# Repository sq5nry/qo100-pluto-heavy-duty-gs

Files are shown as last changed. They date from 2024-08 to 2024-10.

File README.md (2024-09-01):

### qo100-pluto-heavy-duty-gs



# Hello fellow QO-100 aficionados,
Here's another realization of a ground station based on <a href="https://wiki.analog.com/university/tools/pluto/hacking/hardware#revision_b" target="_blank">Pluto</a>. Designed as a sturdy box to be thrown on your roof requires just a single Ethernet cable to talk to. It hosts the great <a href="https://github.com/F1ATB/Remote-SDR" target="_blank">F1ATB Remote-SDR</a> web-based transceiver but when roaming in your LAN you can also enjoy the <a href="https://www.sdr-radio.com/console" target="_blank">G4ELI SDR Console</a> desktop application. Pluto is running on a customized firmware from <a href="https://www.f5uii.net/wp-content/uploads/2021/03/pluto.zip" target="_blank">F5UII</a>. Assemblage of assorted open-source candies makes for a comfortable phone operation.

The device has four panel sockets:
- **RJ-45**: Ethernet+PoE
- **N**: 2.4GHz transmitter output
- **F**: input from LNB
- **SMA**: GPS active antenna

Features:
- operation via a web browser incl. full duplex and live waterfall display
- direct network access to Pluto for 3rd party applications
- push-to-talk automation
- frequency stability from GPS Disciplined Oscillator
- power from PoE only

:warning:Remote operation possible after meeting <a href="https://forum.amsat-dl.org/index.php?thread/3234-remote-operation-via-qo-100/" target="_blank">AMSAT requirements</a>. For the on-demand immediate shutdown capability I'm using a Wi-Fi plug to cut off AC from the PoE injector.

| deployment example | inside the box |
|---|---|
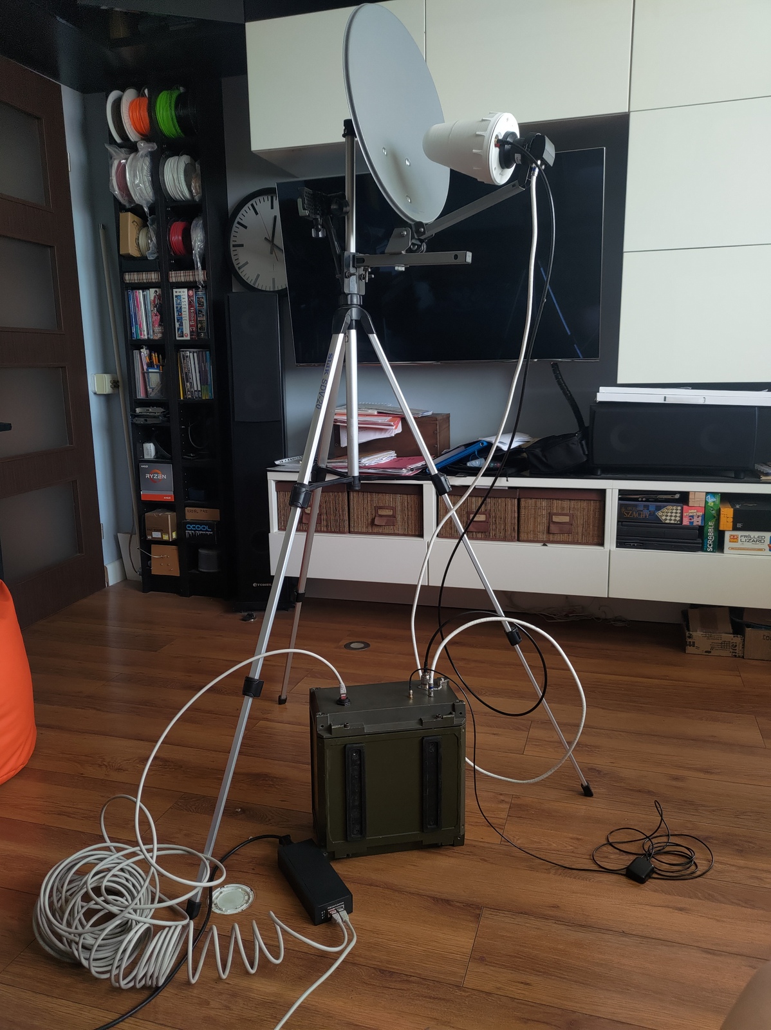
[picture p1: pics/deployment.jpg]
overview
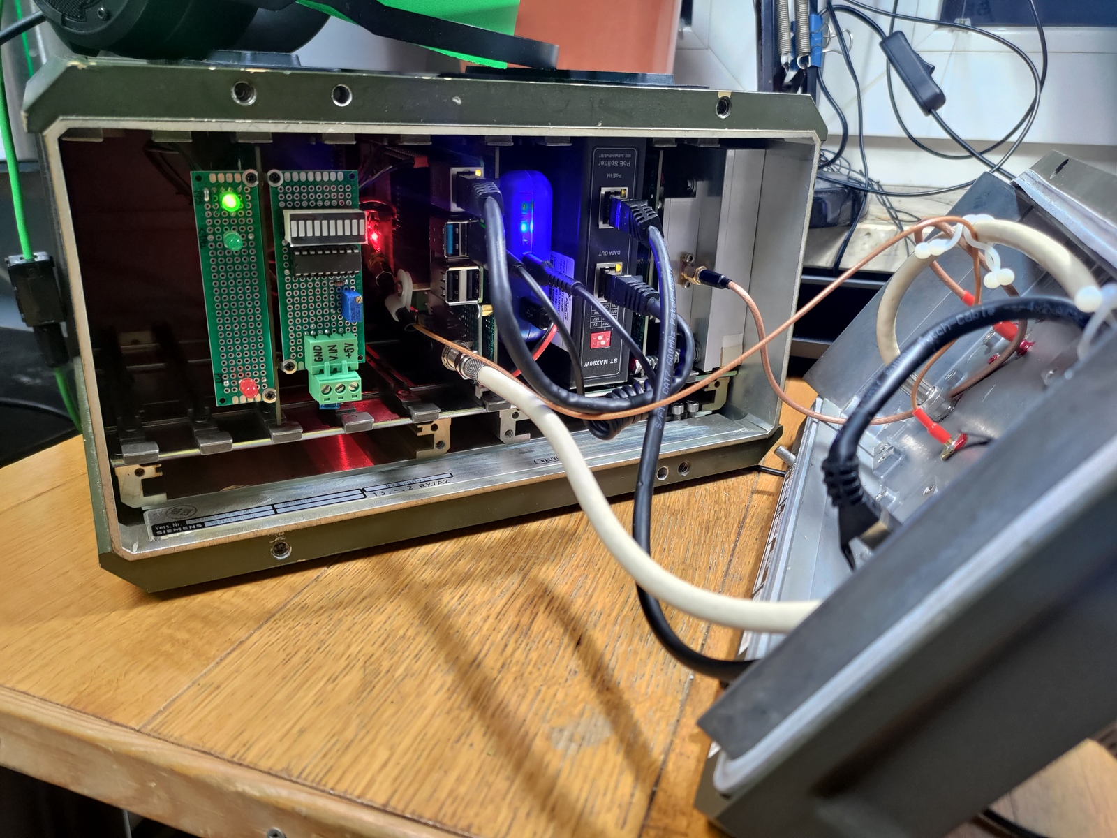
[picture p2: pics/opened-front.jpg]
interior
|  |  |

# Operation
1. Connect to a router with DHCP server via 802.3bt PoE injector offering 90W. 15 meters of SSTP CAT6 works fine. The Raspberry host will be reachable under hostname `remsdr-rpi4`. Configure remote access (eg port forwarding or <a href="https://www.zerotier.com" target="_blank">ZeroTier VPN</a> - installed)
2. Configure the web access <a href="https://remsdr-rpi4/settings.html"  target="_blank">https://remsdr-rpi4/settings.html</a> as described in <a href="https://f1atb.fr/remote-sdr-v5-raspberry-4b-or-orange-pi-image-installation/" target="_blank">https://f1atb.fr/remote-sdr-v5-raspberry-4b-or-orange-pi-image-installation</a>. Finally, navigate to the start page <a href="https://remsdr-rpi4" target="_blank">https://remsdr-rpi4</a>.
3. Alternatively, connect to Pluto locally by specifying `ip:remsdr-rpi4` as the address. Parallel use with the web interface mostly won't work.\
 For SDR Console follow the <a href="https://www.sdr-radio.com/EsHail-2" target="_blank">configuration manual</a>. Connect the USB push-to-talk button and volume knob for best experience.
 
| Arduino Due MIDI controller      |
|----------------------------------|
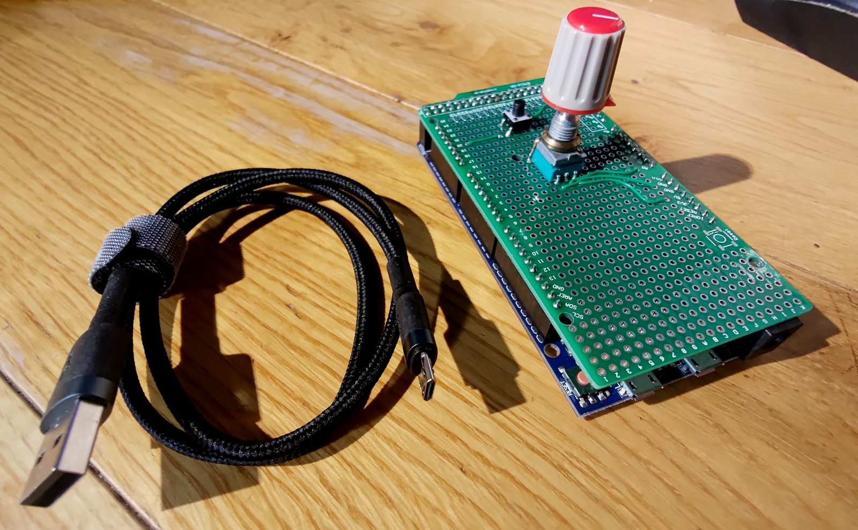
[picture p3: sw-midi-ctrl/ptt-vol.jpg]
Arduino Due MIDI controller
|  |

:warning: Smooth remote work when talking directly to Pluto (eg. SDR Console) requires a low-jitter 20Mbps connection to stream the whole 500kHz NB transponder. Web interface will settle for an ordinary 512kbps link.

# Troubleshooting
1. Restart Pluto via web interface
2. Try turning it off and on again using your remote AC switch. Pluto and software on RPi becomes operational within a minute.
3. Check GPS status on the dashboard panel inside the box
4. Log in via SSH to conduct further diagnosis

# Service manual
General block diagram: [main.pdf](hw-block-diagrams/main.pdf)

## Pluto SDR
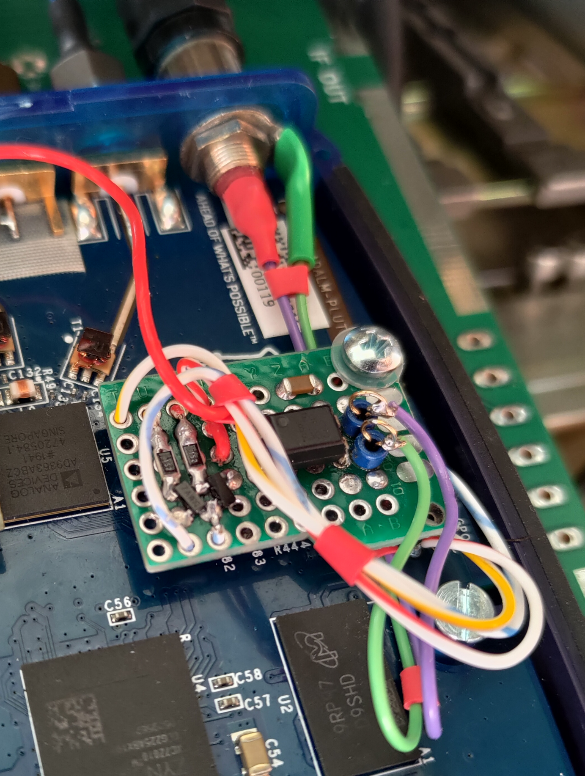
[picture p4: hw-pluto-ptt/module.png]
Built on top of rev. 'B' with two modules added inside the Pluto enclosure: external clock input and PTT output. Flashed with a firmware from F5UII https://www.f5uii.net/wp-content/uploads/2021/03/pluto.zip, here used only for the PTT when working with SDR Console. PTT is active when GPO0 is high and GPO1 is low to counteract transients on Pluto boot (read more here https://hf5l.pl/adalm-pluto-do-qo100-i-nie-tylko/). Here's ready module employing an 817 optocoupler:  \
Schematics diagram: [pluto_ptt.pdf](hw-pluto-ptt/pluto_ptt.pdf)

To install this extension, drill a hole in Pluto's plastic wall and mount a Cinch connector. Fix the PCB by tightening it via existing hole with a longer screw to the mainboard with a 5mm plastic spacer.

External clock feed for Pluto is designed by DM5RM https://forum.amsat-dl.org/index.php?thread/3199-external-clock-for-adalm-pluto/. Operation hinges on a clever idea of creating a small DC component from the clock signal for switching inputs between internal oscillator (not very stable for transmitting) and external one. I've added a blue LED informing that the external clock is active. External clock is generated by GPSDO. There's a blocking capacitor before the isolating transformer as the GPSDO Si5351 output stage doesn't like DC shorts.
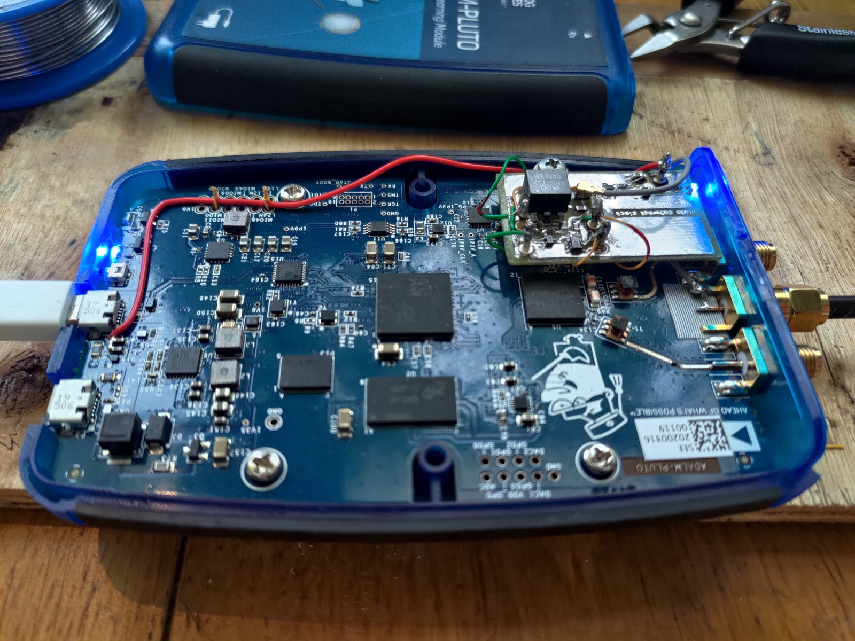
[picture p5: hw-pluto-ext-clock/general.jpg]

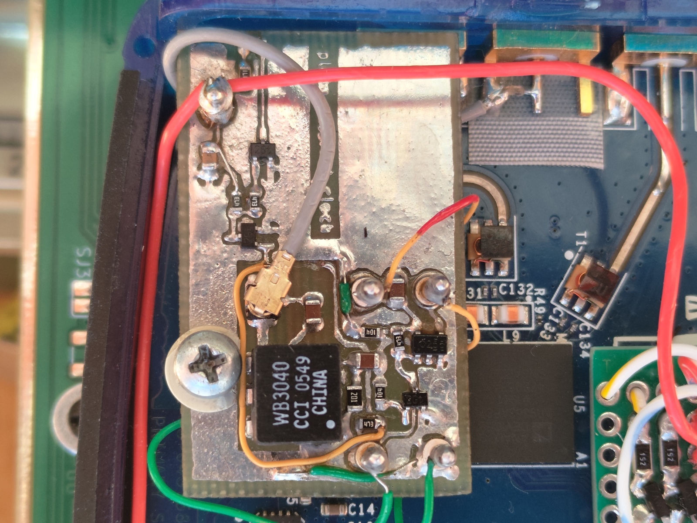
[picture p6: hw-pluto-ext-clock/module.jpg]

Schematics diagram: [pluto_clock_buffer-sch.pdf](hw-pluto-ext-clock/pluto_clock_buffer-sch.pdf) \
To install this extension, drill a hole in Pluto's plastic wall and tight fit an SMA edge connector between RX and TX ports. Place additional insulation tape to avoid bridging grounds of the SMA and that of Pluto. Use a short IPEX pigtail between the SMA connector and the board. Wire four terminal posts parallel to the onboard oscillator (1.8V, OUT, E/D, GND). Fix the PCB by tightening it via existing hole in a similar manner as the PTT extension. Place another wire from USB for 5V supply (attach to the filtering cap as shown in the picture); this line also routes to the PTT board.

A no-name 2.4GHz power amplifier delivers abt. 10W at 24V & 2A. It is mounted on a heatsink, further pressed against the enclosure wall. Internally it comprises three stages: SAW filter, MMIC pre-amplifier, and final stage with a directional coupler for forward power measurement. PTT powers the MMIC and biases the final stage hence the ~90mA current consumption.
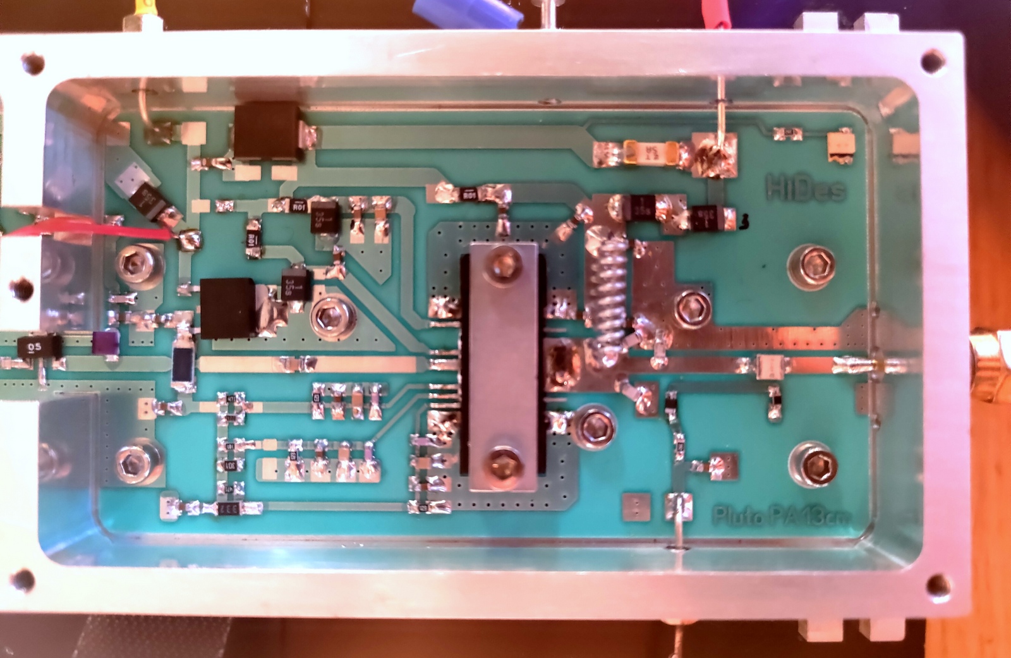
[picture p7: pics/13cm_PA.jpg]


Receive path consists of an LNB and the bias-tee. I have added an option of switching LNA voltage for H/V polarisation control, for future wideband use.
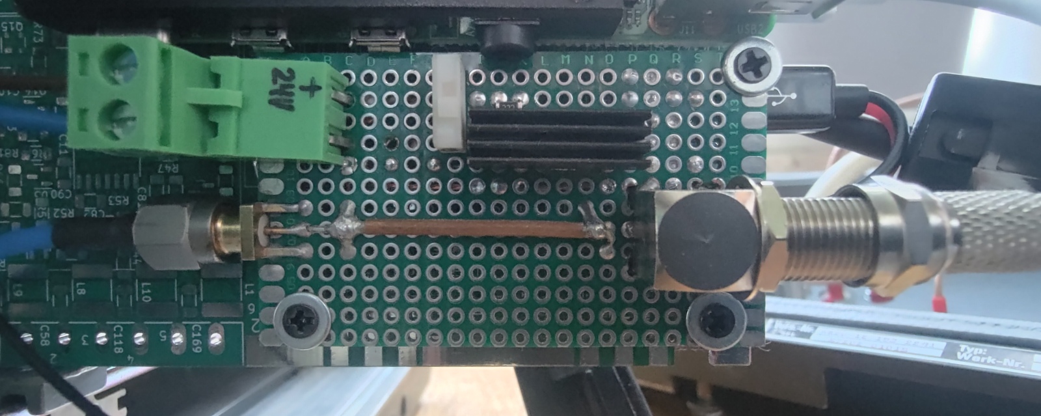
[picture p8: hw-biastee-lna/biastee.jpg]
 \
Schematics diagram: [pluto_biastee.pdf](hw-biastee-lna/pluto_biastee.pdf)

Finally, Pluto is powered from two USB plugs as advised by ADI.

## Raspberry Pi 4B
The platform is running the image from F1ATB https://f1atb.fr/remote-sdr-v5-raspberry-4b-or-orange-pi-image-installation/ and is serving a web-based Remote SDR application for receiving and transmitting via Pluto. In addition, Pluto's libiio endpoint is exposed externally so that you can connect to it via SDR Console or another client. In this mode, RPi is acting as a router between Pluto's network and RPi host. One GPIO pin is the PTT output and connects to the control board. \
Network script for exposing Pluto over RPi's ethernet interface: [ext-pluto](scripts/ext-pluto). Copy it under _/etc/network/interfaces_.

## Power and PTT control
Power supply is provided from a power regulator of the PoE splitter, preset to 24V and rated at 90W max. It goes directly to:
- the 2.4GHz power amplifier
- bias-tee and LNA power regulator
- 5V 8A regulator for all other modules

Each downstream line is protected by a resettable polymer fuse. \
Schematics diagram: [pluto_pwr_ctrl.pdf](hw-psu-ctrl/pluto_pwr_ctrl.pdf) 

| 5V regulator close-up                           |
|-------------------------------------------------|
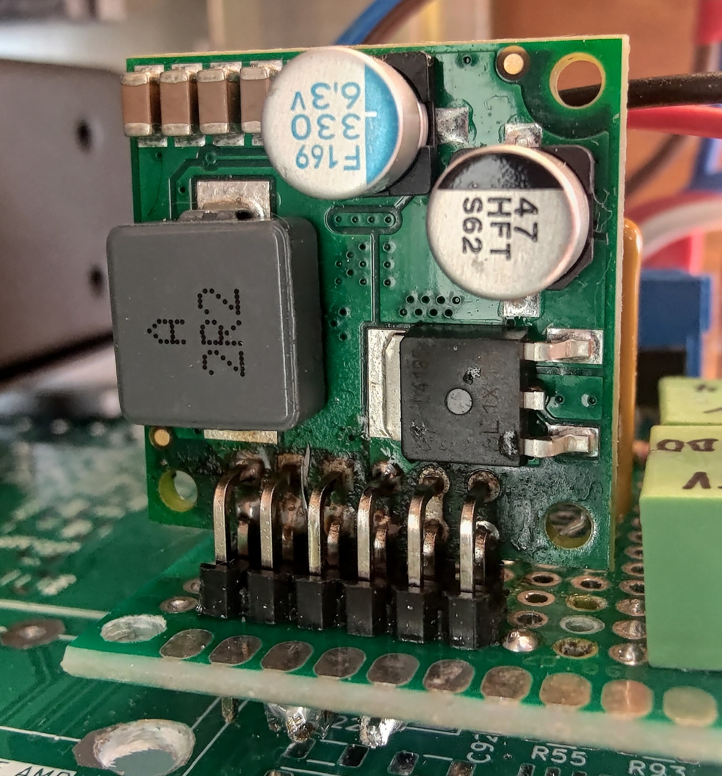
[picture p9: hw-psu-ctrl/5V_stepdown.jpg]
|  |

On the same board is mounted PTT circuitry that sums both PTT inputs (from RPi GPIO and Pluto PTT) and switches on PTT voltage for PA (abt. 90mA of current consumption). Q1 and Q2 form a high-side switch where the first stage is actually a two-transistor wired-OR gate with the second transistor being the optocoupler inside Pluto. You'll have noticed that the PTT coming from RPi's GPIO is unnecessary since Pluto tells you when it's transmitting by activating the optocoupler. Yet you might not want to upgrade the firmware which adds this and stay with the web-application only. Another reason is PTT via GPIO is asserted as soon as you click PTT on the web page and it may take tenths of milliseconds if by Pluto. This delay is virtually unnoticeable when working in SDR Console.

## GPSDO
Based on projects of W3PM (https://github.com/W3PM/GPS-Si5351-VFO-QEX-JUL-AUG-2015), SQ1GU (http://sq1gu.tobis.com.pl/pl/syntezery-dds/44-generator-si5351a) and SP3VSS (https://sp3vss.eu/moje-konstrukcje/gpsdo-generator-synchronizowany-gps/).
It generates fixed 40MHz frequency _disciplined_ by the GPS PPS signal and consists of three common-off-the-shelf modules: Arduino Nano (a clone), Si5351 synthesizer and a GPS receiver.
This is a minimal implementation of the oscillator, without display and buttons. I have introduced the following changes to the source code:
- removed handling of display and buttons
- added initial frequency correction (about 4kHz) so that at least one synchronization round can be saved. Value is hardcoded and based on a coarse one-time measurement.
- added a duplicated PPS output via GPIO for diagnostics which drives a LED at 0,5Hz and 50% duty.
- code refactoring and clean-up

Sketch: [gpsdo_minimal.ino](hw-gpsdo/gpsdo_minimal.ino) \
Block diagram: [gpsdo.pdf](hw-gpsdo/gpsdo.pdf) \
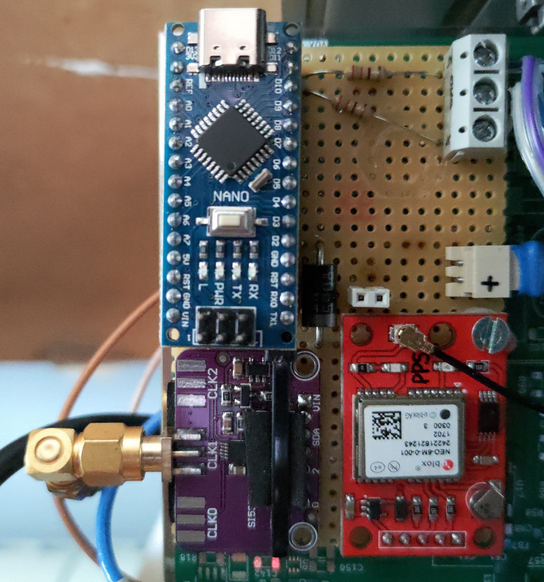
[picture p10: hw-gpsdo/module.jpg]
 \
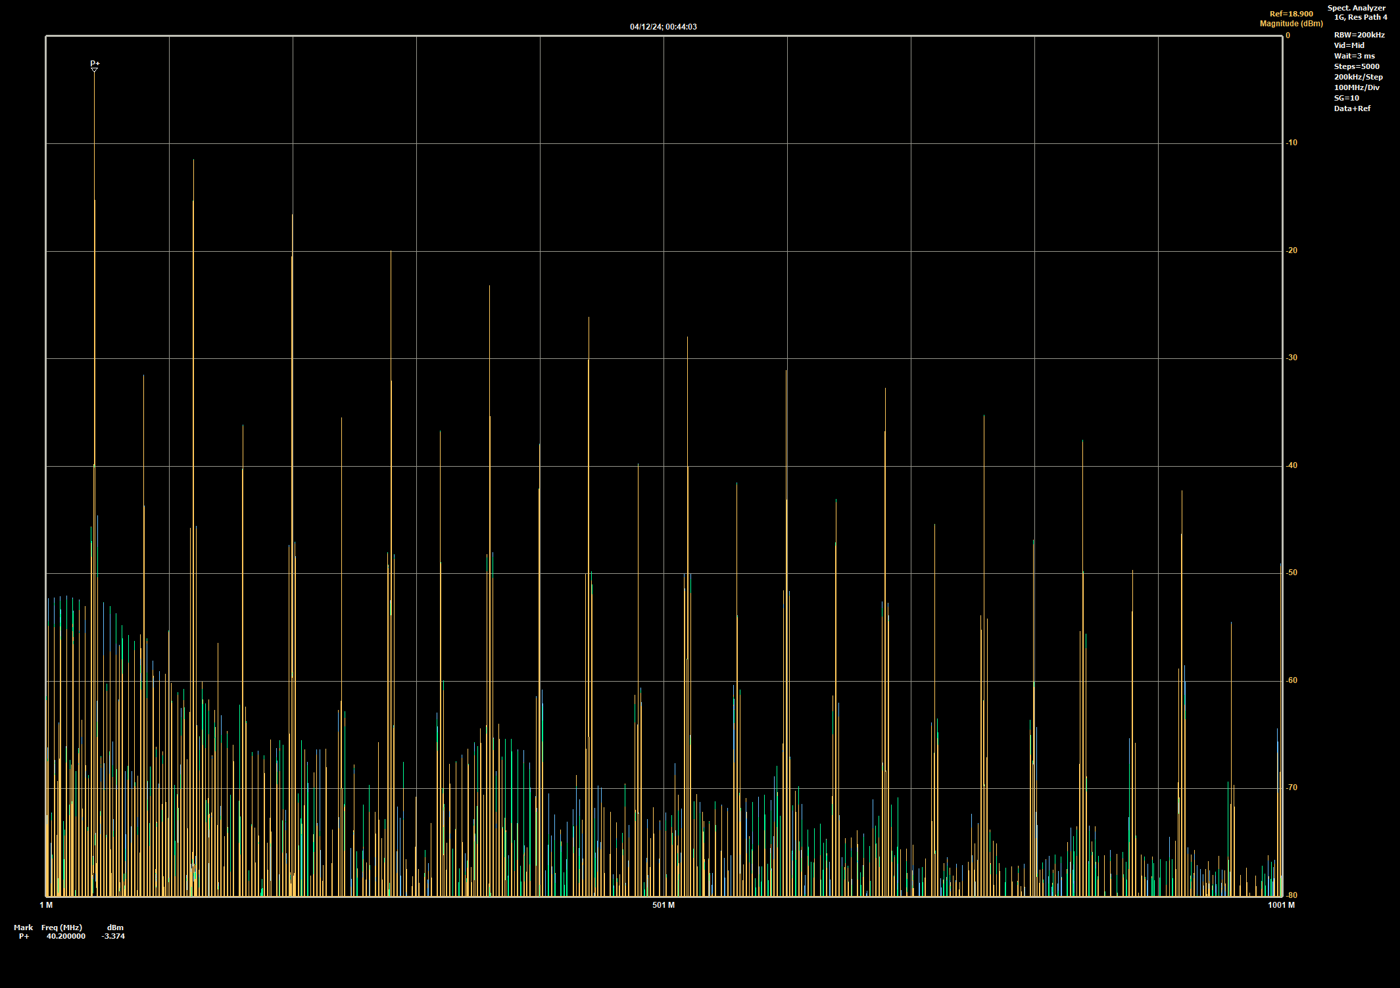
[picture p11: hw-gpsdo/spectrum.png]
Output spectrum: 
The spectrum shows a decent pattern for square wave harmonics, however 2nd order components are relatively high and decay only up to -50dBc at 1GHz. Notable are numerous spikes spaced at 200kHz, most probably being a residue from the internal Si5351 PLL stage. I haven't noticed any audible difference between this GPSDO and internal Pluto clock when working on the narrowband transponder. Wideband use might require a cleaner signal with respect to the jitter but I haven't checked that.

The diagnostics board houses two LEDs showing status of the GPSDO:
- pulse-per-second indicator showing the GPS receiver has signal
- high-accuracy (<1Hz) lock achieved

In addition:
- red LED when TX is engaged
- bargraph for TX output level
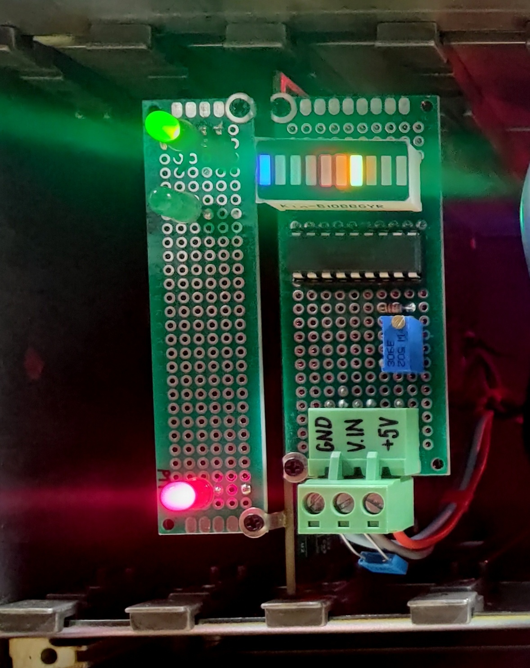
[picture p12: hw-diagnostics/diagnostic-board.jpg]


## Transmit button and volume knob
SDR Console application accepts MIDI-based devices to control transceiver functions. A simple implementation for PTT and volume knob can be realized using an Arduino module supporting a USB device natively. I've used a clone: _Due R3 SAM3X8E CORTEX-M3_. 
I based on the project presented here: https://go.musiconerd.com/code-gen-basic \
Sketch: [midi_controller_Duo_v2.ino](sw-midi-ctrl%2Fmidi_controller_Duo_v2/midi_controller_Duo_v2.ino)

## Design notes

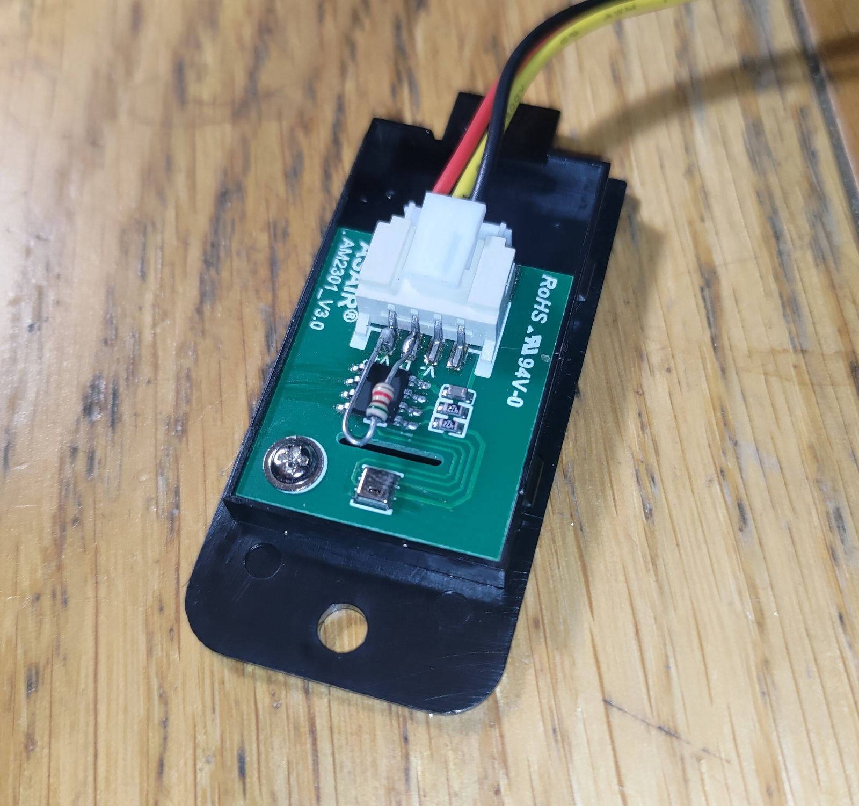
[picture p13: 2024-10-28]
pics/humidity_sensor.jpg

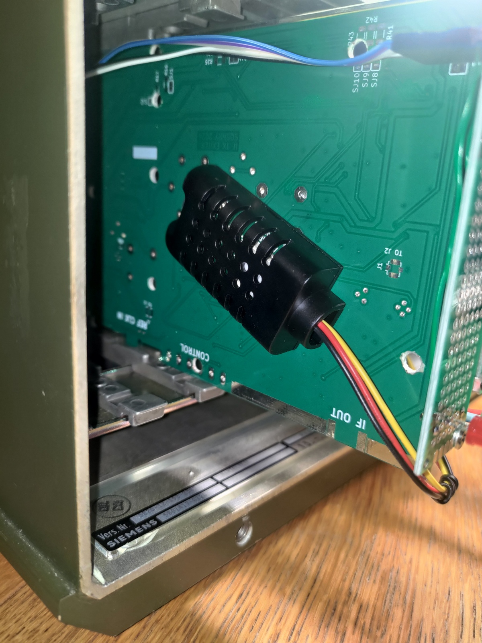
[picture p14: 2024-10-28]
pics/humidity_sensor_2.jpg

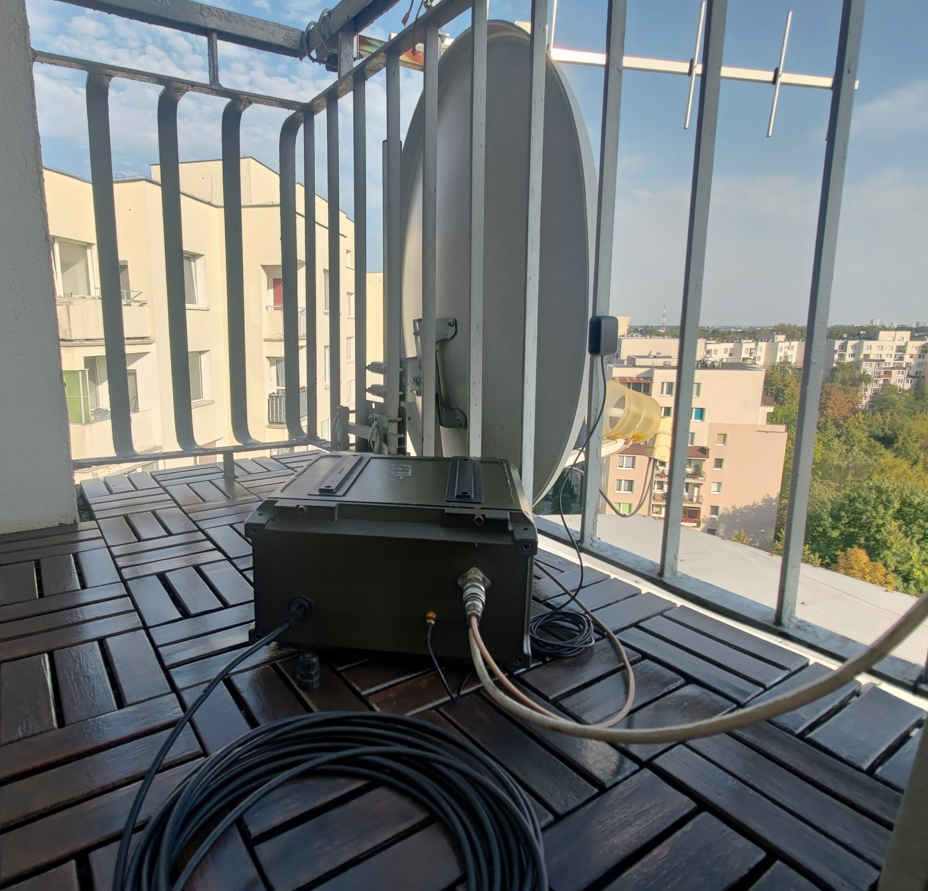
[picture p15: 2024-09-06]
pics/deployment-2.jpg

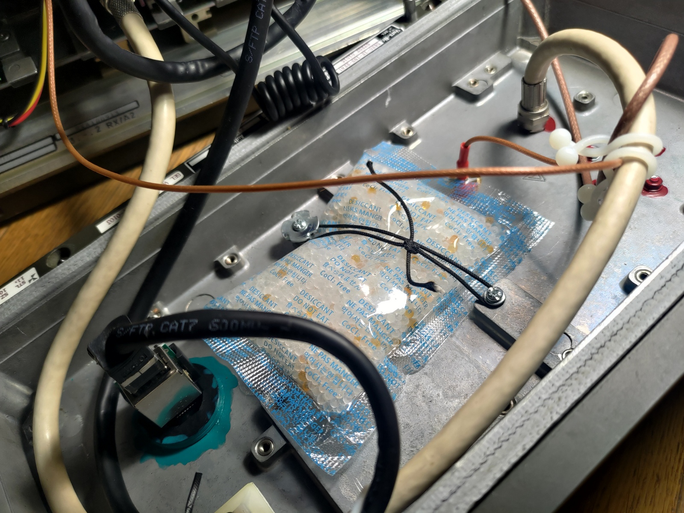
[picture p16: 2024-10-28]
pics/silica_gel.jpg

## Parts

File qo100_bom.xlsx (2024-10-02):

Pozycja | Szczegóły zakupu | Cena brutto PLN
Raspberry Pi 4 model B WiFi DualBand Bluetooth 2GB RAM 1,8GHz Indeks: RPI-14646 | BOTLAND zamówienie nr: 1142826 | 209
Obudowa-radiator Alloy Heatsink do Raspberry Pi 4B - aluminiowa - czarna Indeks: DNG-18127 | BOTLAND zamówienie nr: 1142826 | 33.15
D36V50F5 - przetwornica step-down 5V 8A - Pololu 4091 Indeks: PLL-1639 | BOTLAND zamówienie nr: 1142826 | 110
Przemysłowy rozdzielacz POE 90 W Instalacja ścienna DIN Wyjście 12 V/16 V/24 V/48 V | https://pl.aliexpress.com/item/1005005555843936.html | 200.29
Wtryskiwacz POE 90w 10G 802.3af/at/BT | https://pl.aliexpress.com/item/1005001325819218.html | 169.88
PRZEMYSŁOWA ALUMINIOWA OBUDOWA HERMETYCZNA DUŻA | https://allegro.pl/oferta/przemyslowa-aluminiowa-obudowa-hermetyczna-duza-8604877948 | 70
Antena Square GPS SMA - 3m Indeks: PSC-14775 | BOTLAND zamówienie nr: 1142826 | 26.31
Moduł GPS GY-NEO6MV2 z anteną | allegro, Sklep msalamon.pl | 27.99
Nano V3.0 z USB-C zgodny z Arduino | allegro, Sklep msalamon.pl | 28.25
SI5351A Generator sygnałów 8 kHz - 160 MHz | allegro, Sklep msalamon.pl | 28.25
Arduino DUE R3 - Atmel SAM3X8E - Cortex 84MHz - klon | Sklep ABC-RC zamówienie numer 62860 | 84.05
Płytka uniwersalna do Arduino MEGA PA02 | GOTRONIK.PL Numer zamówienia: 53071 | 12.6
Gniazdo N do obudowy herm. | https://allegro.pl/oferta/gniazdo-n-na-kabel-rg174-do-obudowy-4-sruby-15201846869 | 19.4
Pigtail SMA-wt / SMA-wt RG402 SemiFlex 20cm v1 | https://allegro.pl/oferta/pigtail-sma-wt-sma-wt-rg402-semiflex-20cm-v1-15345918431 | 37.46
GNIAZDO RJ-45 HERMETYCZNE IP67 DO OBUDOWY NA PANEL | https://allegro.pl/oferta/gniazdo-rj-45-hermetyczne-ip67-do-obudowy-na-panel-12378895084 | 80
Microconnect SSTP CAT6 15M kabel sieciowy Szary S/FTP (S-STP) | https://allegro.pl/oferta/microconnect-sstp-cat6-15m-kabel-sieciowy-szary-s-ftp-s-stp-15291351191 | 88.99
Microconnect 0.25m Cat7 S/FTP kabel sieciowy Czarny 0,25 m S/FTP (S-STP) | https://allegro.pl/oferta/microconnect-0-25m-cat7-s-ftp-kabel-sieciowy-czarny-0-25-m-s-ftp-s-stp-15291289192 | 38.99
RADIATOR P52317 100x150x25mm 1,4 K/W | https://allegro.pl/produkt/radiator-p52317-100x150x25mm-1-4-k-w-44661f8f-eca2-451e-b04c-e11f473a7ae2 | 26
Kabel USB - Micro USB ARKS 0.5 m Czarny spiralka | https://www.electro.pl/telefony-i-smartfony/akcesoria-do-telefonow/kable-i-przewody/kabel-usb-micro-usb-arks-0-5-m-czarny | 7.99
Gniazdo;F;żeńskie;kątowe 90°;THT;na panel FC-017 | TME Numer faktury: 1241214848 F | 7.54
RF2-06A-T-21-50-G Gniazdo;SMA;żeńskie;proste;RG178(A,B);zaciskanie;na panel Producent: ADAM TECH; Symbol producenta: RF2-06A-T-21-50-G; Zgodność RoHS | TME Numer faktury: 1241214848 F | 17
Higrometr +termometr 1-wire | https://botland.com.pl/czujniki-multifunkcyjne/1884-czujnik-temperatury-i-wilgotnosci-dht21-am2301-w-obudowie-5904422373269.html | 33.92
Desykant krzemionkowy | https://allegro.pl/oferta/orange-silica-gel-2x50g-pomaranczowy-zel-krzemionkowy-pochlaniacz-wilgoci-15242886034 | 6
Pluto rev. B | n/a
Wzmacniacz mocy 13cm | n/a
 |  | 1278.57

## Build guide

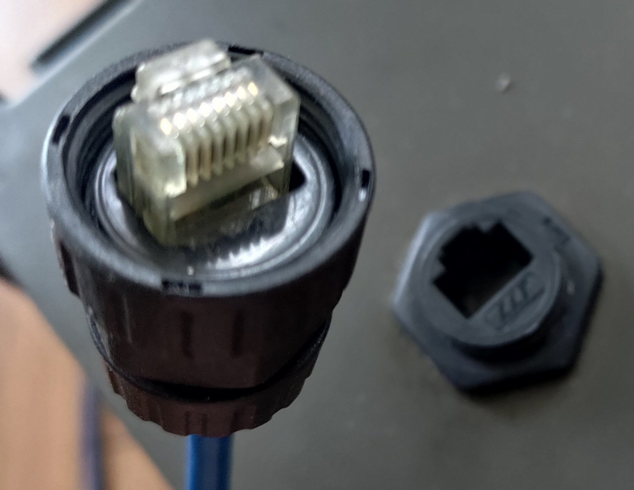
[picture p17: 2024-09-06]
pics/eth_wiring_2.jpg

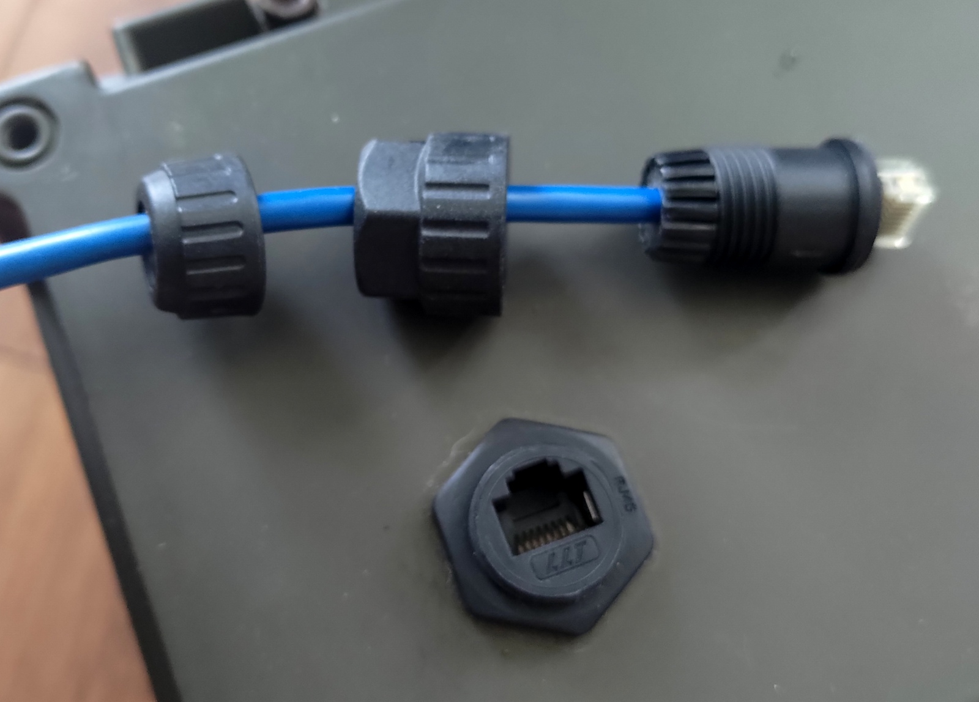
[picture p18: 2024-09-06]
pics/eth_wiring_3.jpg

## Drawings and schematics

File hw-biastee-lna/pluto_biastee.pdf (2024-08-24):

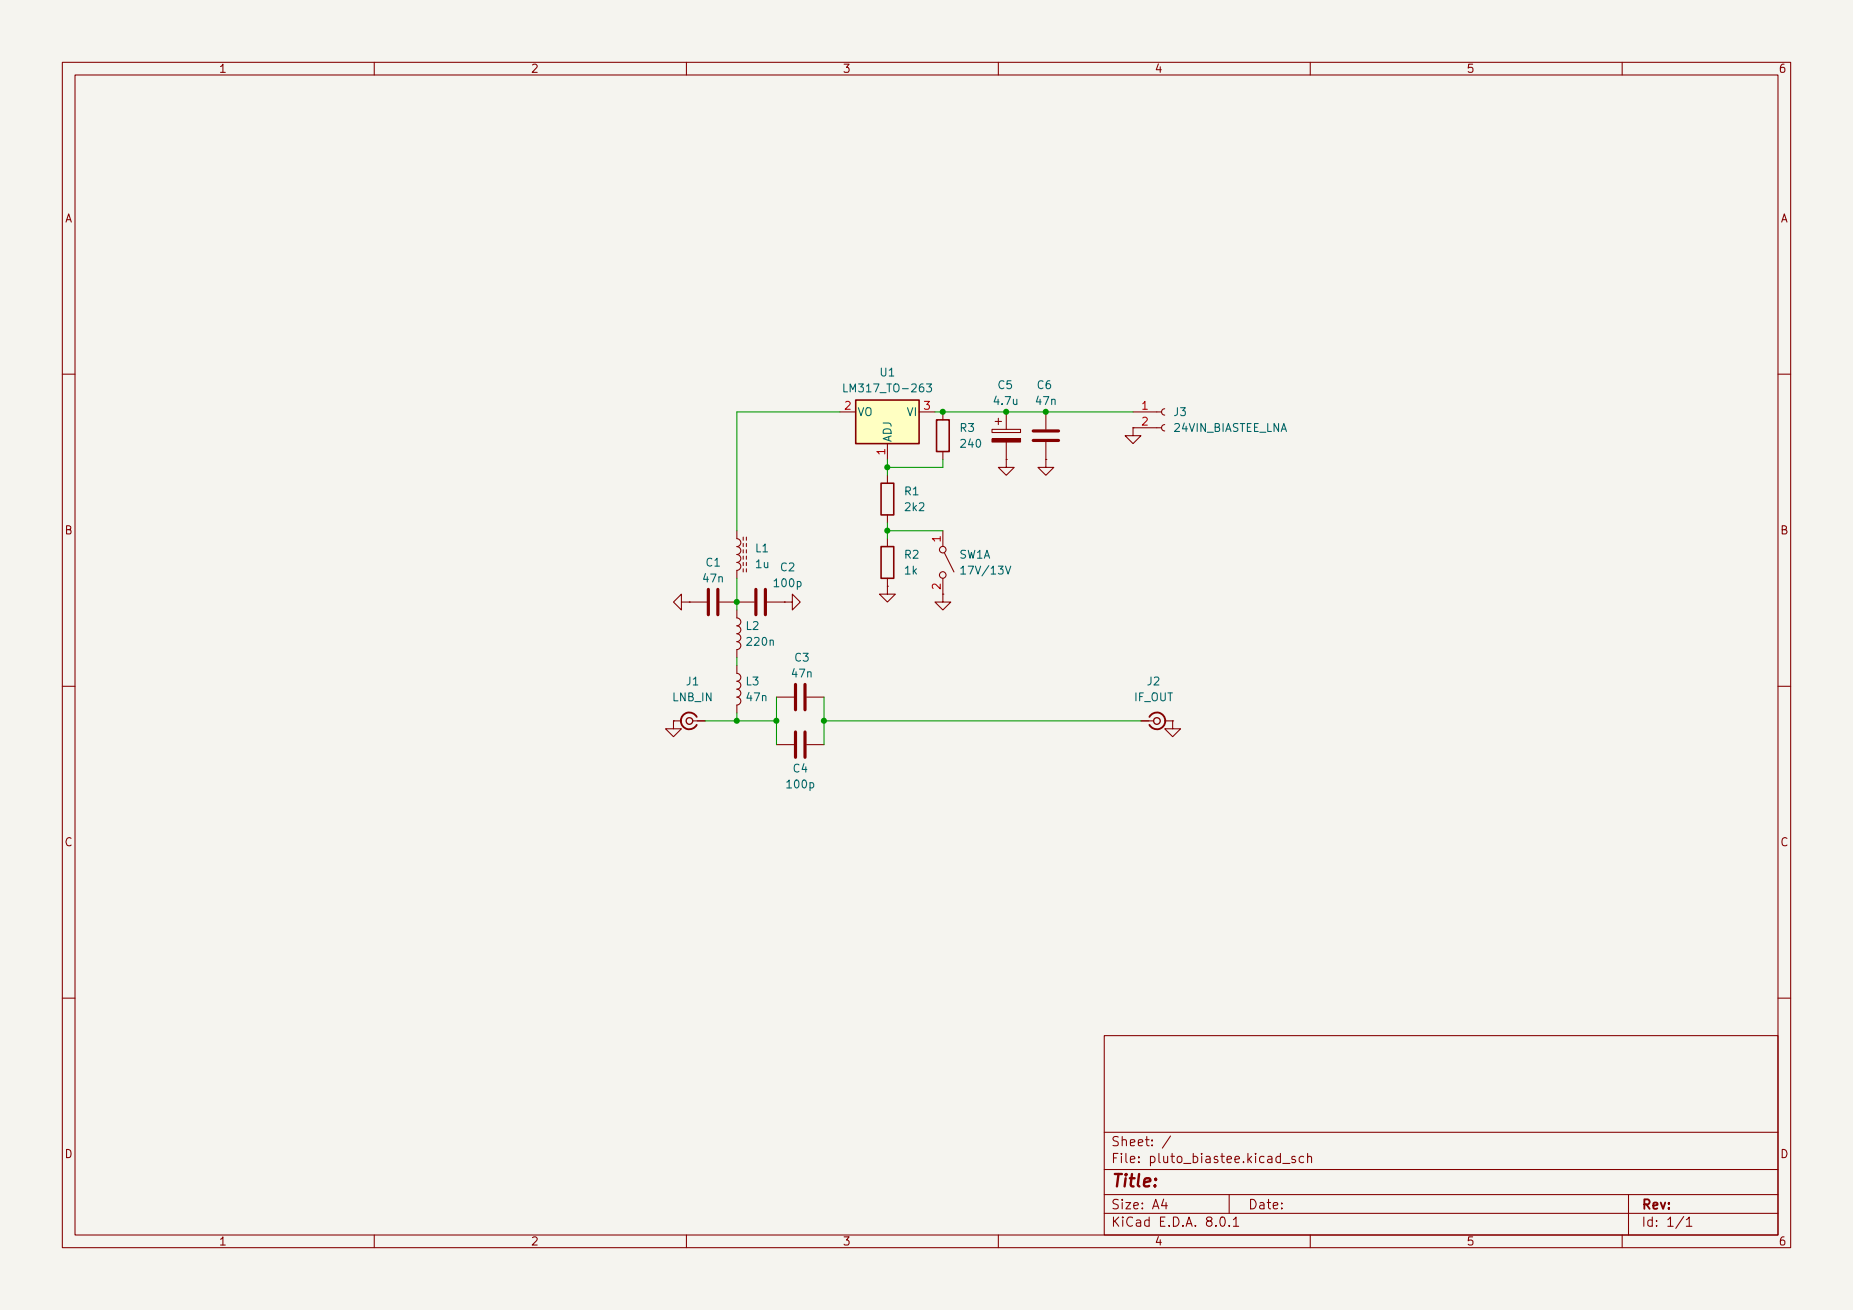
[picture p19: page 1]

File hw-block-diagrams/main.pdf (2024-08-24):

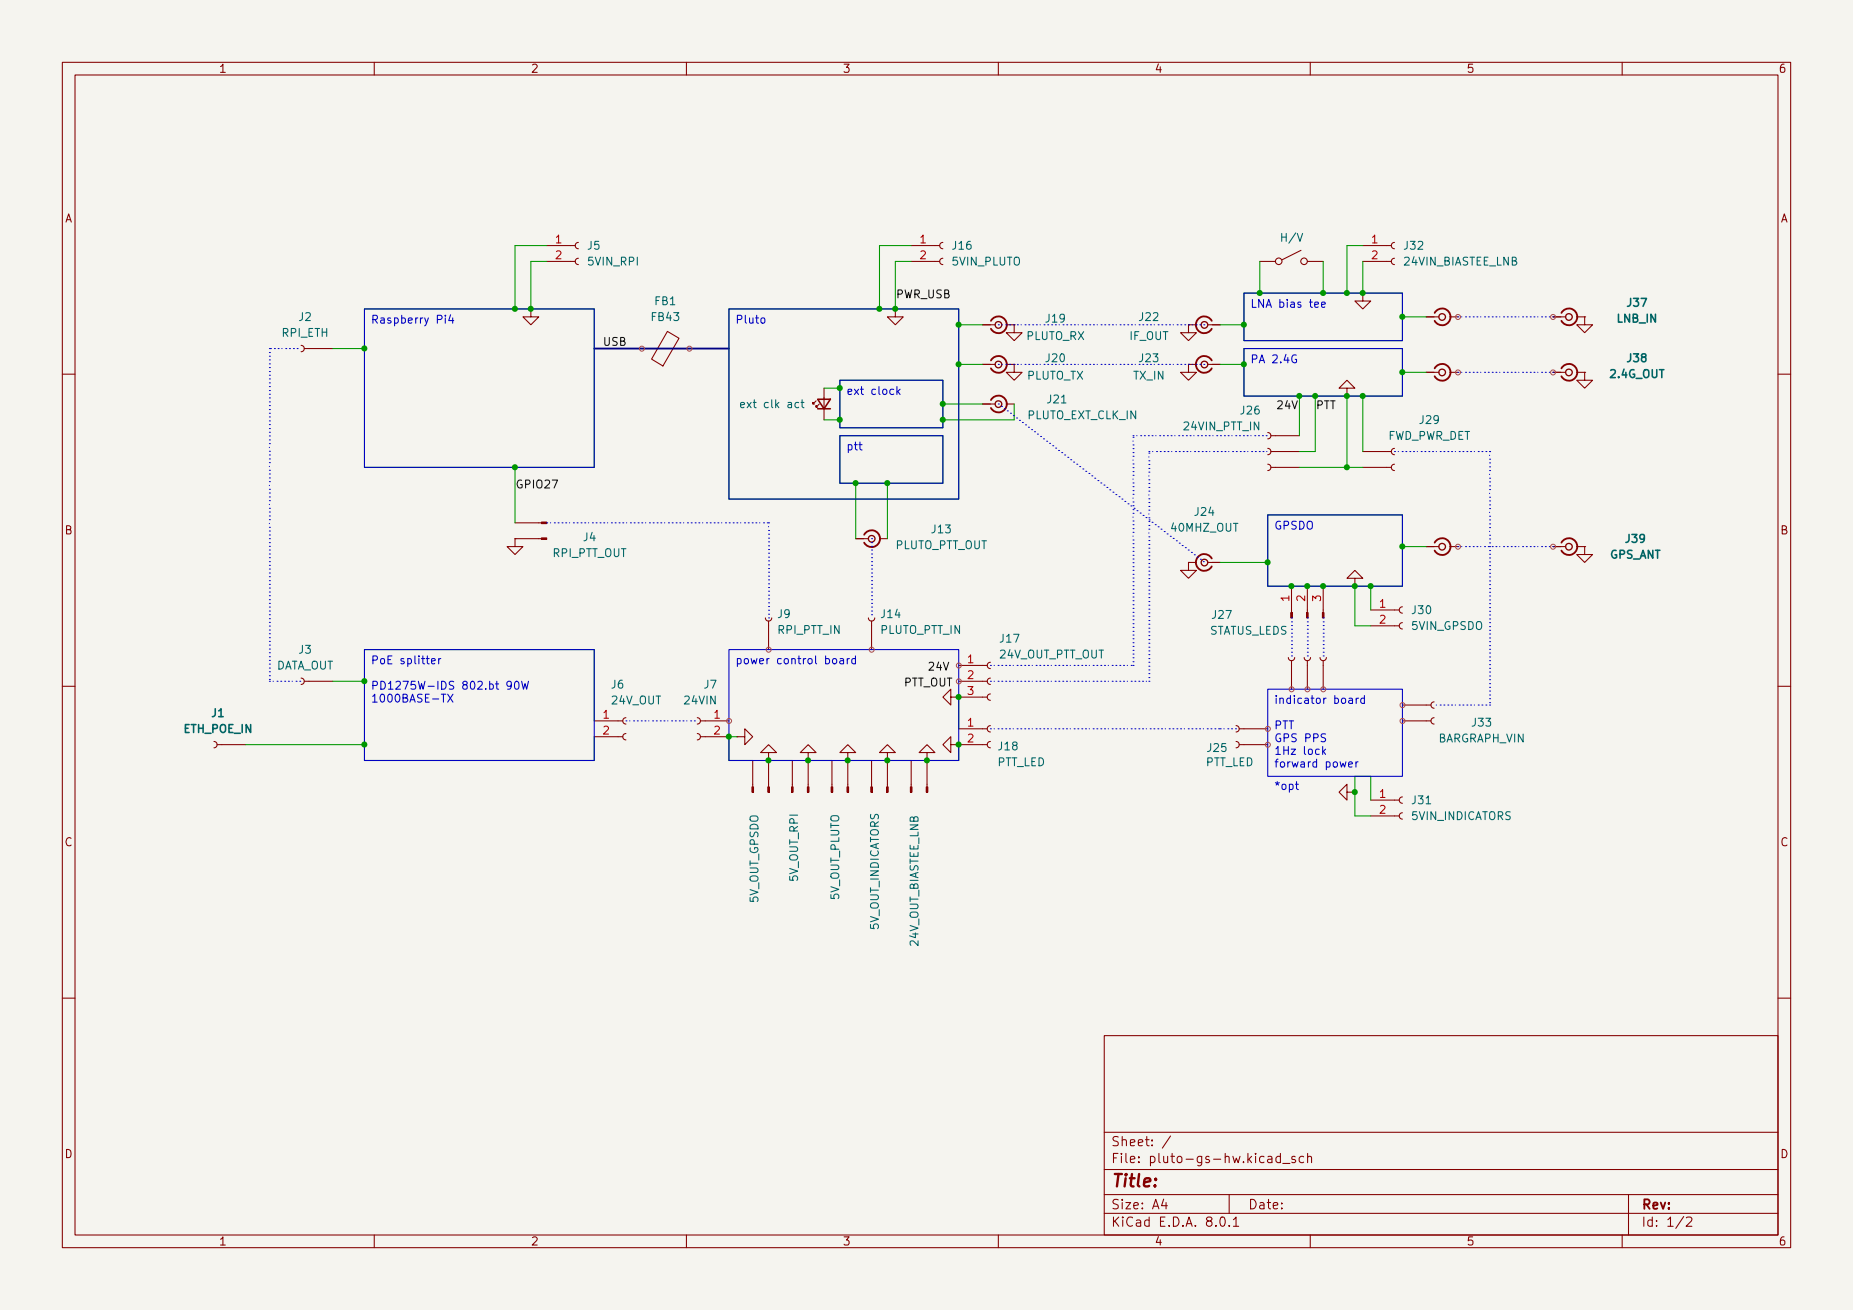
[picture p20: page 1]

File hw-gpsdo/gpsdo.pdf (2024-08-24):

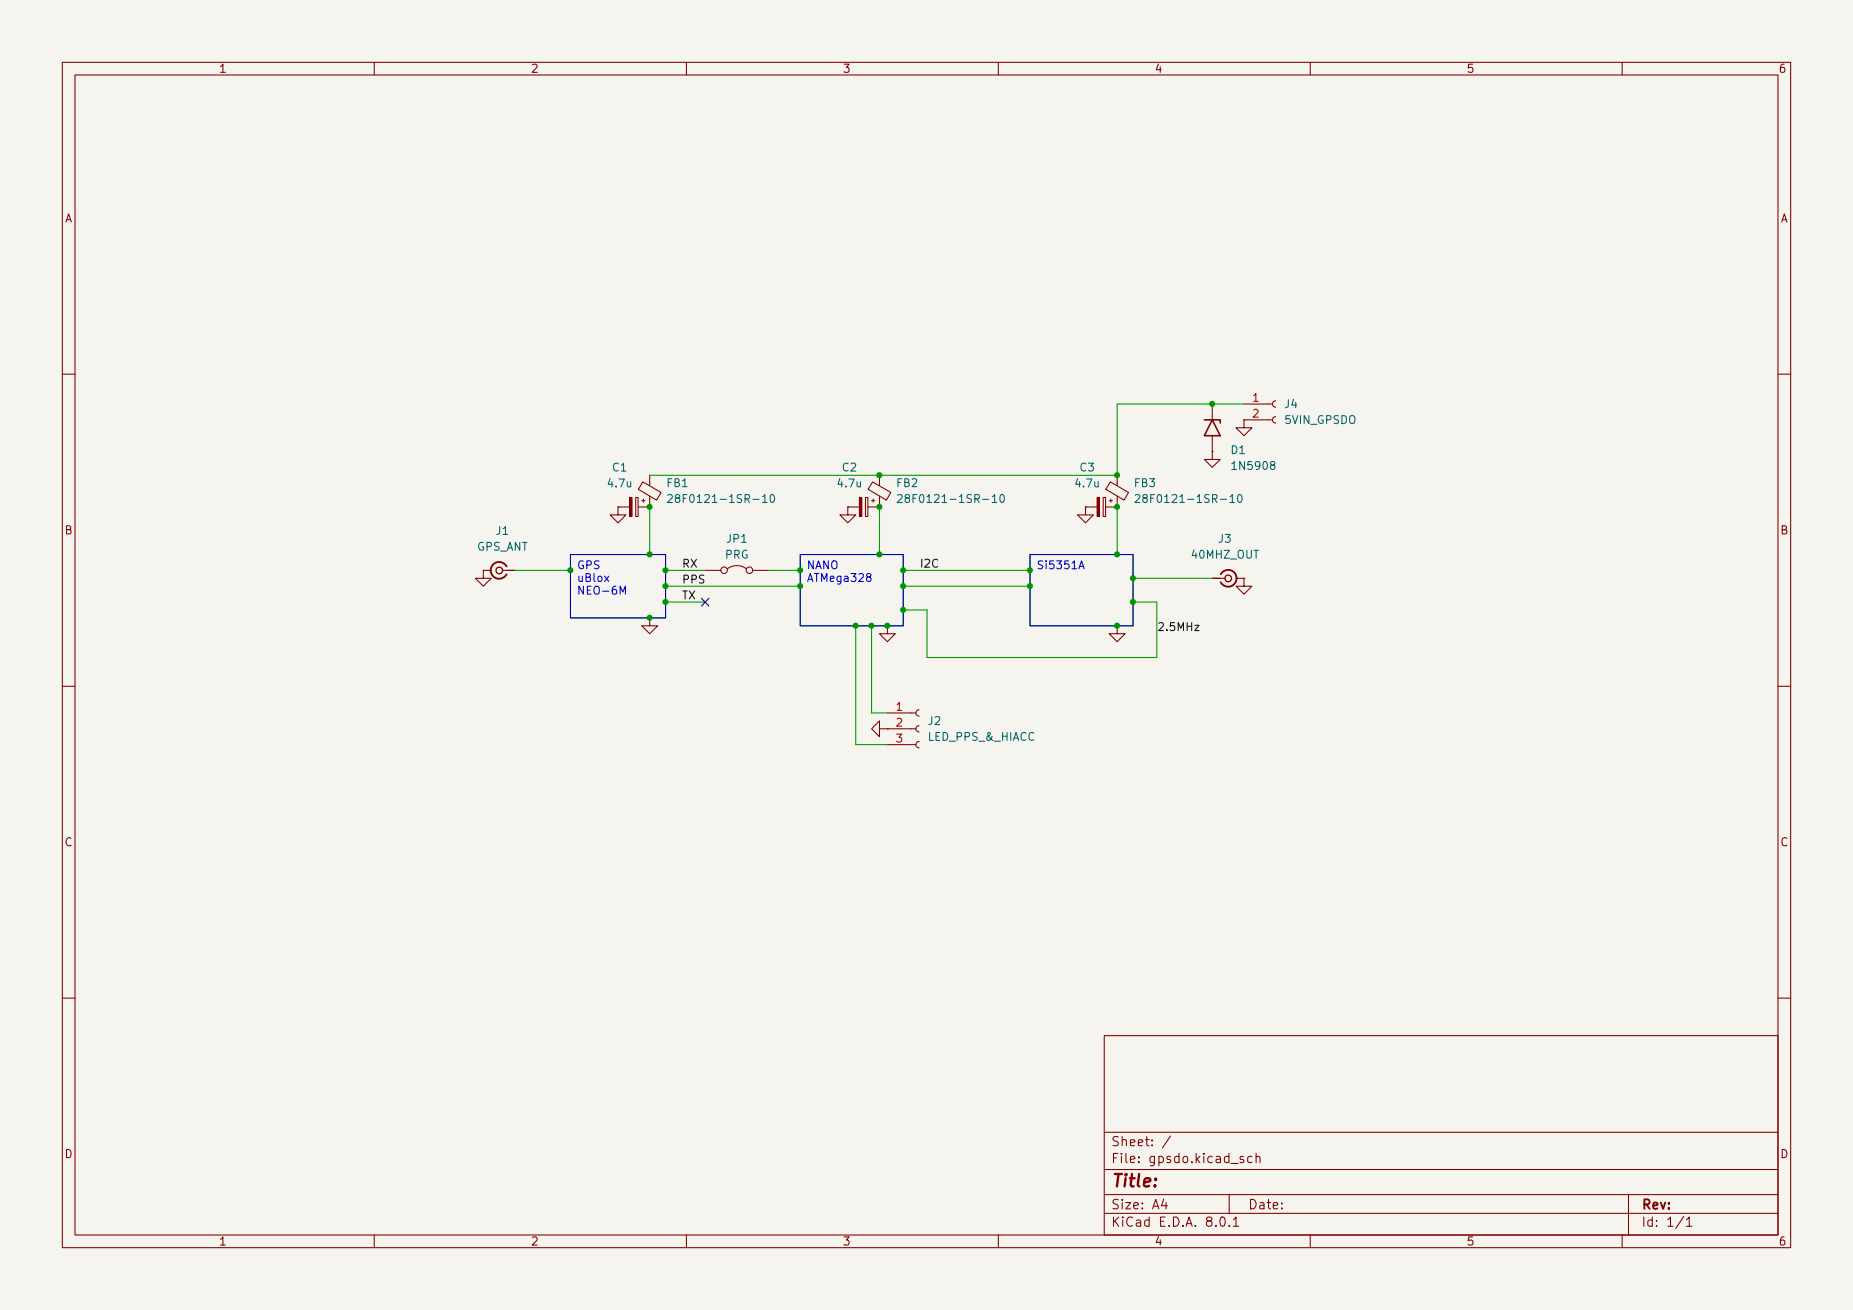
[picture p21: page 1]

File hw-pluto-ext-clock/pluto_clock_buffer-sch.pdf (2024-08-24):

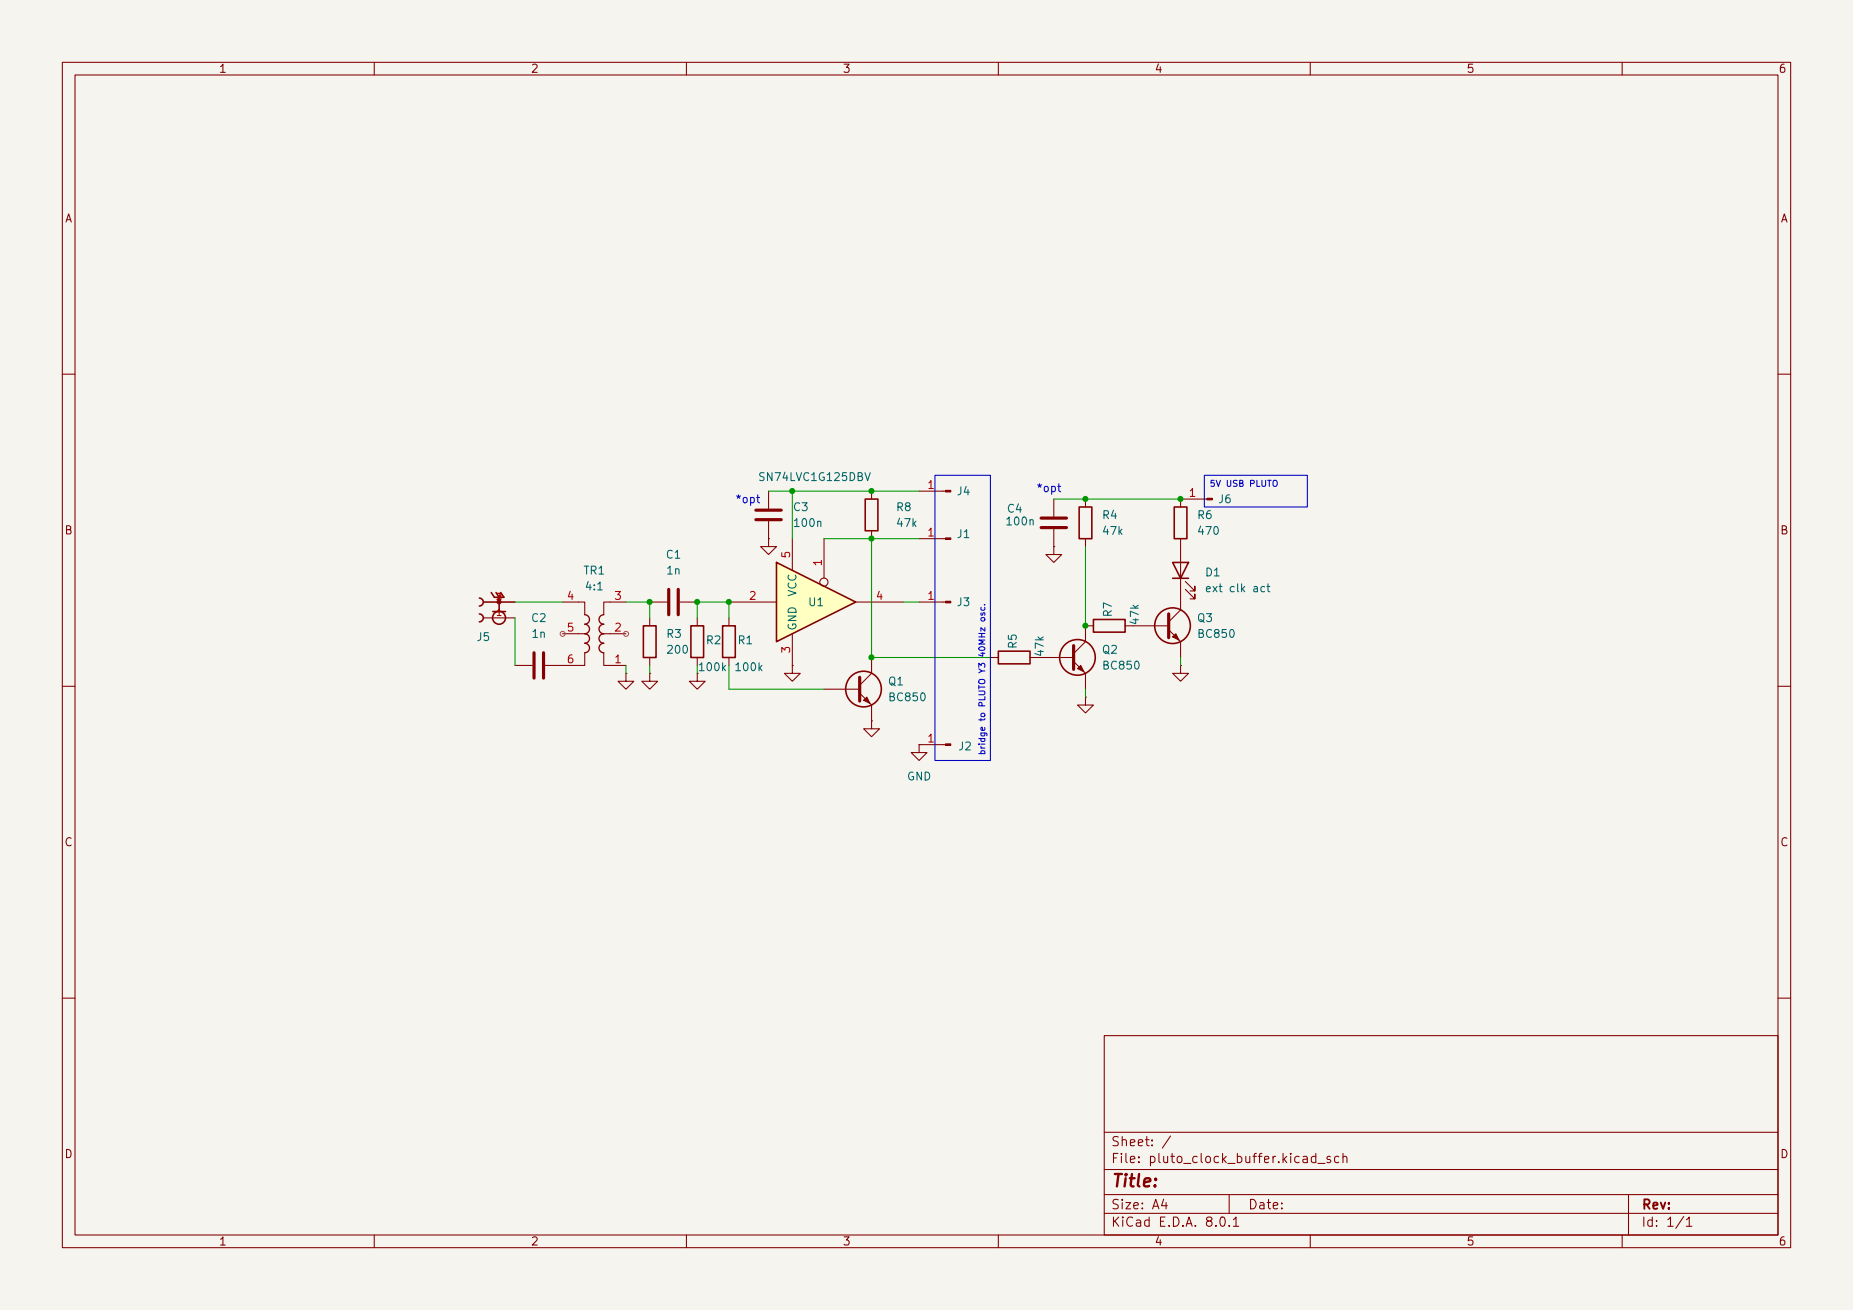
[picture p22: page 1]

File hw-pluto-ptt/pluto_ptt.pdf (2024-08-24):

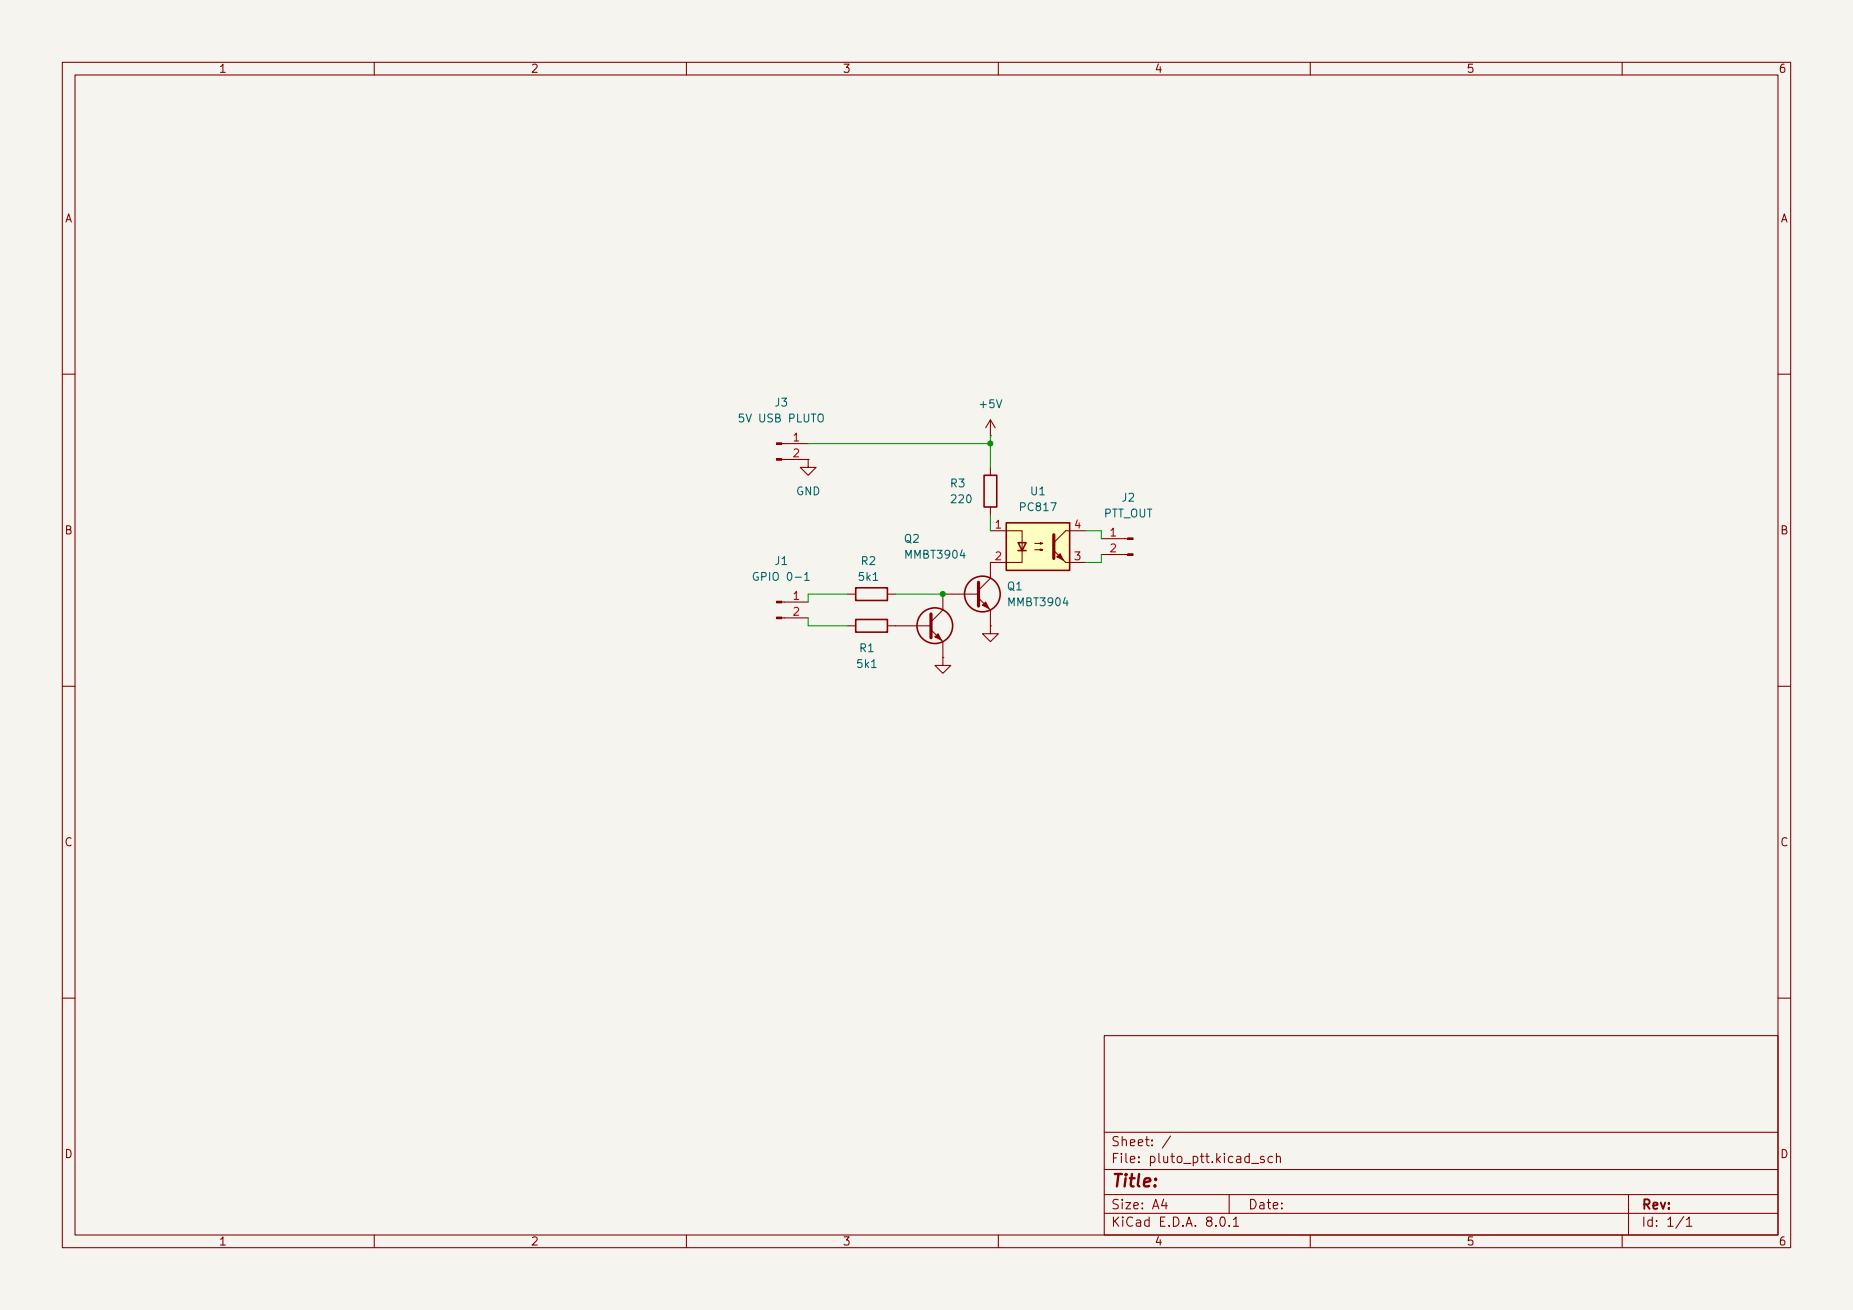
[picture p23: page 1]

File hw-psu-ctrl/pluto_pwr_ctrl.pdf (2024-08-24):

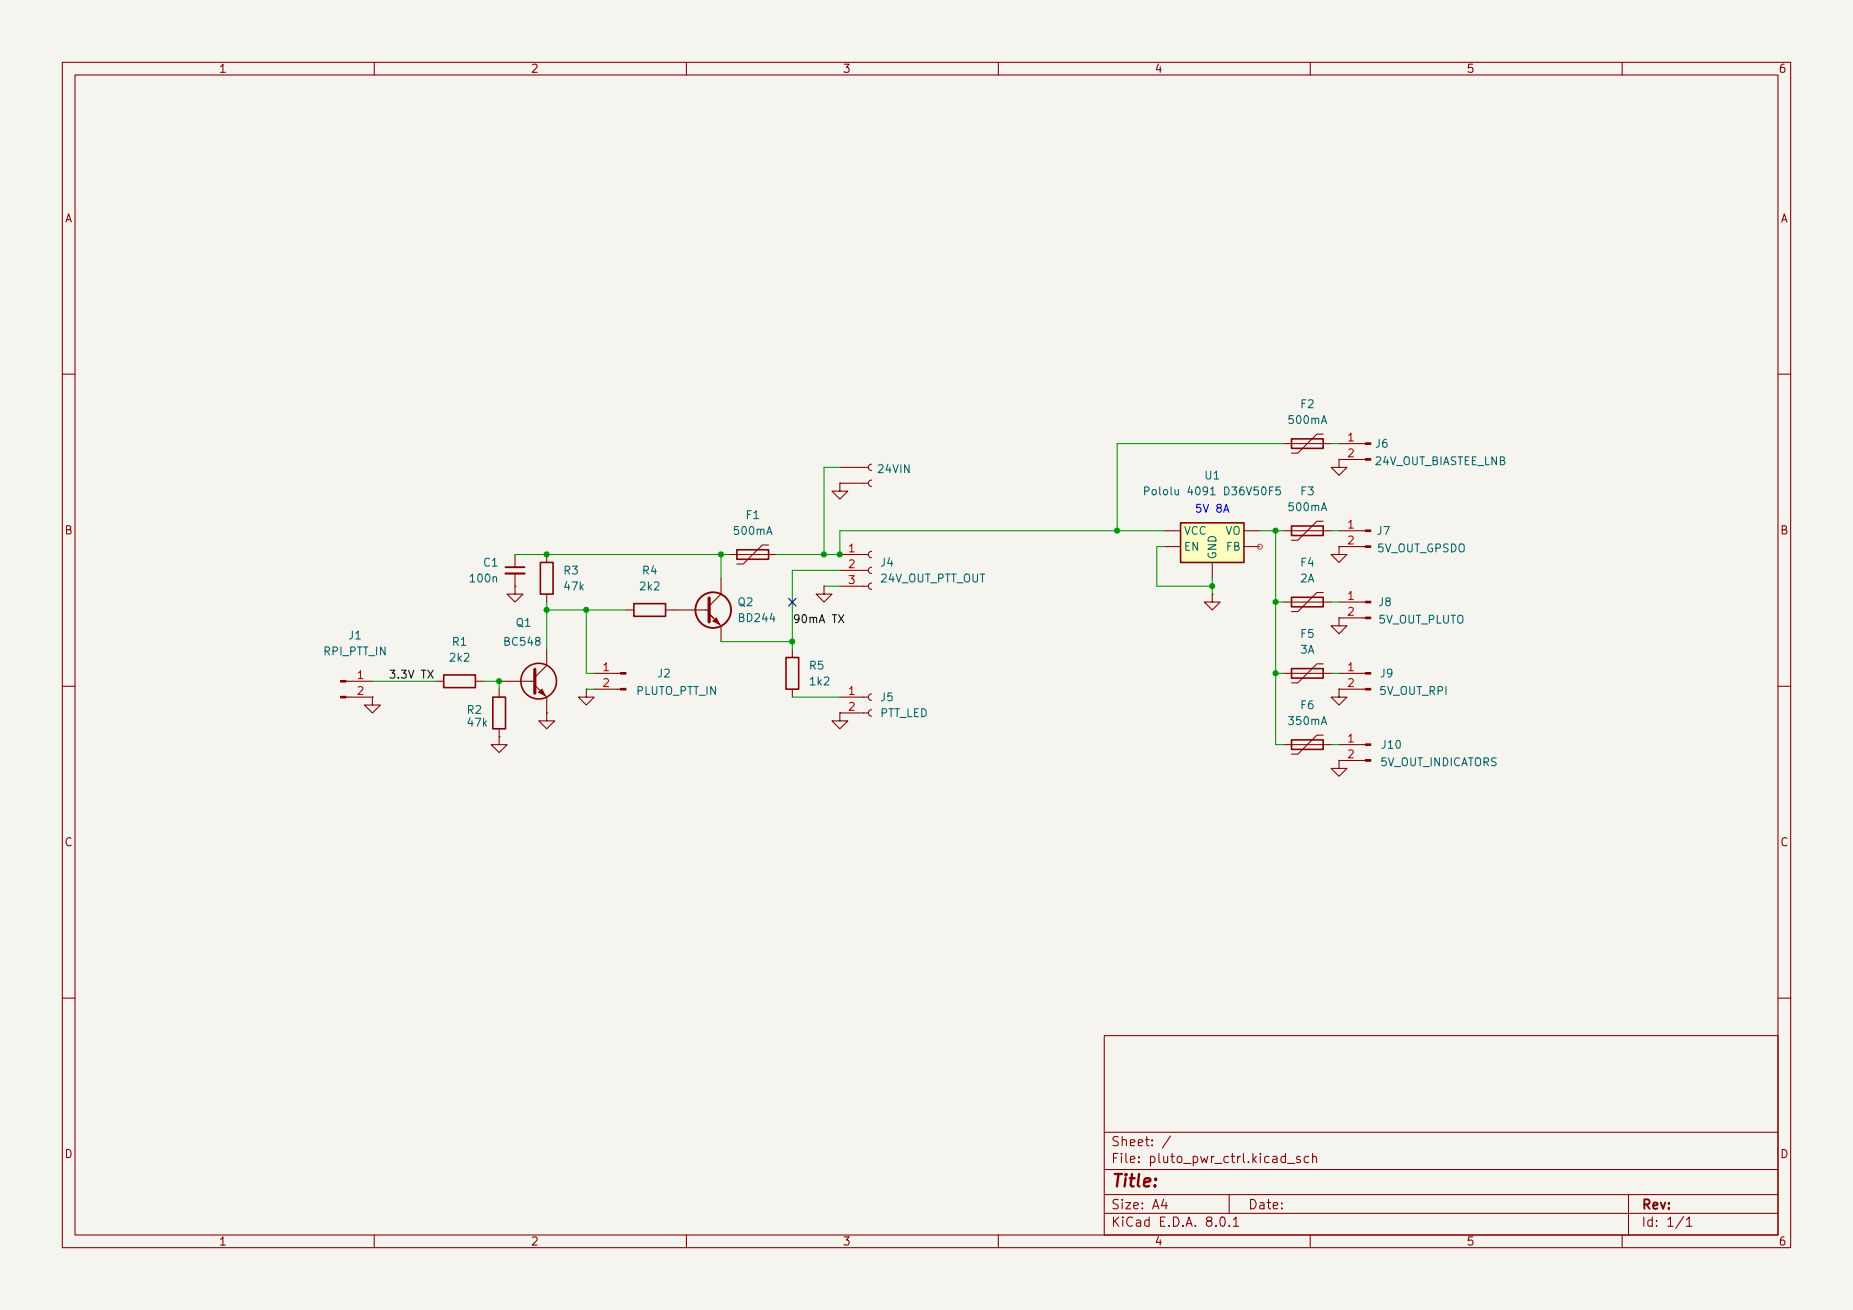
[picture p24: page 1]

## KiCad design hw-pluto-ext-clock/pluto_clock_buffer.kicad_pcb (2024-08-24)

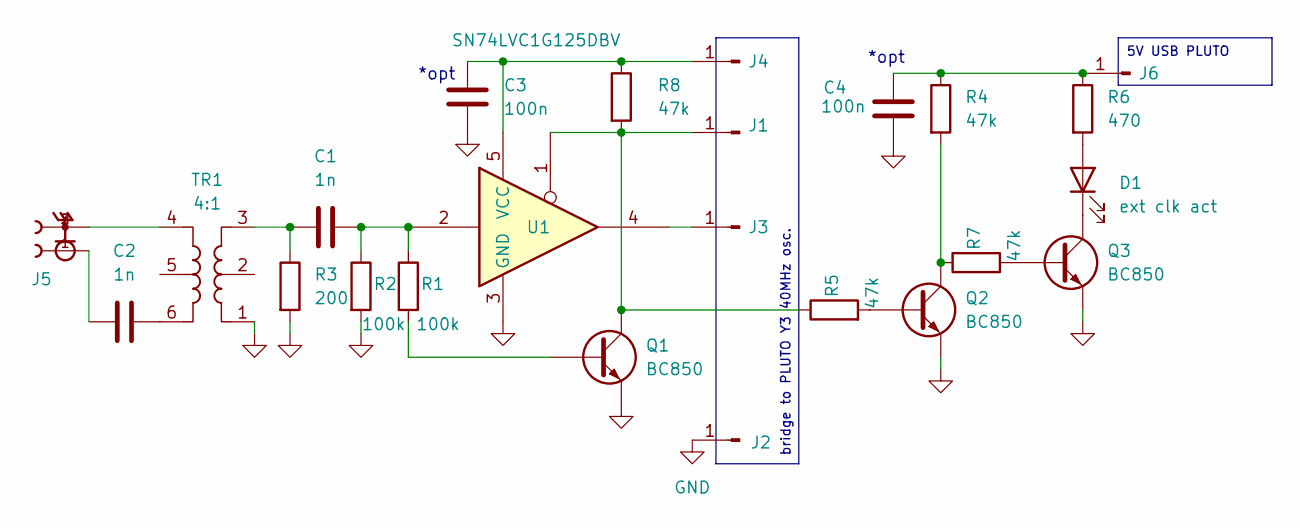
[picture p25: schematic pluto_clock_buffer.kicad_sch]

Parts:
C1, C2: 1n; C_0805_2012Metric
C3, C4: 100n; C_0805_2012Metric
D1: ext clk act; LED_0603_1608Metric
J1, J2, J3, J4, J6: Conn_01x01_Pin; Pin_D1.0mm_L10.0mm
J5: 20279-001E-03; IPEX_20279-001E-03; PARTREV 32
Q1, Q2, Q3: BC850; SOT-323_SC-70_Handsoldering
R1, R2: 100k; R_0603_1608Metric
R3: 200; R_0603_1608Metric
R4, R5, R7, R8: 47k; R_0603_1608Metric
R6: 470; R_0603_1608Metric
TR1: 4:1; Mini-Circuits_CD637_H5.23mm
U1: SN74LVC1G125DBV; SOT-23-5

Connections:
GND: C3.2, C4.2, J2.1, Q1.2 (E), Q2.2 (E), Q3.2 (E), R2.2, R3.2, TR1.1, U1.3 (GND)
unnamed: C1.1, R1.1, R2.1, U1.2
unnamed: C1.2, R3.1, TR1.3
unnamed: C2.1, TR1.6
unnamed: C2.2, J5.1
unnamed: D1.2 (A), R6.2
unnamed: D1.1 (K), Q3.3 (C)
unnamed: J1.1, Q1.3 (C), R5.1, R8.2, U1.1
unnamed: J3.1, U1.4
unnamed: C3.1, J4.1, R8.1, U1.5 (VCC)
unnamed: J5.2, J5.3, TR1.4
unnamed: C4.1, J6.1, R4.1, R6.1
unnamed: Q1.1 (B), R1.2
unnamed: Q2.1 (B), R5.2
unnamed: Q2.3 (C), R4.2, R7.1
unnamed: Q3.1 (B), R7.2

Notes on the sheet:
5V USB PLUTO
bridge to PLUTO Y3 40MHz osc.
*opt

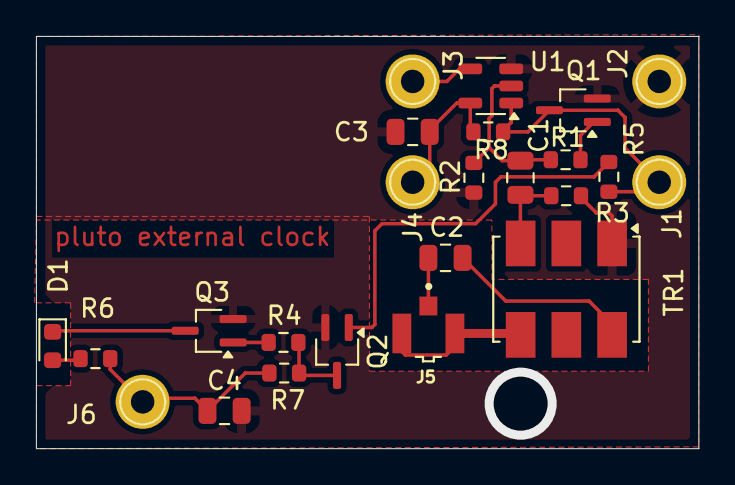
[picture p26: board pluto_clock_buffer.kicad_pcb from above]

Board: 2 copper layers, 36.8 x 22.9 mm, 24 parts (0 on the bottom side), 16 nets.

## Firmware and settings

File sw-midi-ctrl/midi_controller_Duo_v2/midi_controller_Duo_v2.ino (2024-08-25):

/*
  Based on Sketch built by Gustavo Silveira (aka Music Nerd)
  Modified by Dolce Wang

  This code is only for Arduinos that use ATmega32u4 (like Micro, Pro Micro, Leonardo...)
  Remember to also assign the correct board in the IDE (like Tools / Boards / Sparkfun AVR / Pro Micro...)

Updates from SQ5NRY for SDR Console control:
- single PTT button
- single pot on A0
*/

// Change any fields with //**


// LIBRARY

#include "MIDIUSB.h"  

// BUTTONS
const int NButtons = 1; //***  total number of buttons
const int buttonPin[NButtons] = {20}; //*** define Digital Pins connected from Buttons to Arduino; (ie {10, 16, 14, 15, 6, 7, 8, 9, 2, 3, 4, 5}; 12 buttons)
                                            
int buttonCState[NButtons] = {};        // stores the button current value
int buttonPState[NButtons] = {};        // stores the button previous value

      
// debounce
unsigned long lastDebounceTime[NButtons] = {0};  // the last time the output pin was toggled
unsigned long debounceDelay = 50;    //** the debounce time; increase if the output flickers


// POTENTIOMETERS
const int NPots = 1; //*** total number of pots (knobs and faders)
const int potPin[NPots] = {A0}; //*** define Analog Pins connected from Pots to Arduino; Leave nothing in the array if 0 pots {}
int potCState[NPots] = {0}; // Current state of the pot; delete 0 if 0 pots
int potPState[NPots] = {0}; // Previous state of the pot; delete 0 if 0 pots
int potVar = 0; // Difference between the current and previous state of the pot

int midiCState[NPots] = {0}; // Current state of the midi value; delete 0 if 0 pots
int midiPState[NPots] = {0}; // Previous state of the midi value; delete 0 if 0 pots

const int TIMEOUT = 300; //* Amount of time the potentiometer will be read after it exceeds the varThreshold
const int varThreshold = 10; //* Threshold for the potentiometer signal variation
boolean potMoving = true; // If the potentiometer is moving
unsigned long PTime[NPots] = {0}; // Previously stored time; delete 0 if 0 pots
unsigned long timer[NPots] = {0}; // Stores the time that has elapsed since the timer was reset; delete 0 if 0 pots


// MIDI Assignments 
byte midiCh = 1; //* MIDI channel to be used
byte note = 36; //* Lowest note to be used; 36 = C2; 60 = Middle C
byte cc = 1; //* Lowest MIDI CC to be used


// SETUP
void setup() {

  // Baud Rate
  // 31250 for MIDI class compliant | 115200 for Hairless MIDI

  // Buttons
  // Initialize buttons with pull up resistors
  for (int i = 0; i < NButtons; i++) {
    pinMode(buttonPin[i], INPUT_PULLUP);
  }

}

////
// LOOP
void loop() {

  buttons();
  potentiometers();

}

////
// BUTTONS
void buttons() {

  for (int i = 0; i < NButtons; i++) {

    buttonCState[i] = digitalRead(buttonPin[i]);  // read pins from arduino

    if ((millis() - lastDebounceTime[i]) > debounceDelay) {

      if (buttonPState[i] != buttonCState[i]) {
        lastDebounceTime[i] = millis();

        if (buttonCState[i] == LOW) {

          // Sends the MIDI note ON 
          
         // use if using with ATmega32U4 (micro, pro micro, leonardo...)
          noteOn(midiCh, note + i, 127);  // channel, note, velocity
          MidiUSB.flush();


        }
        else {

          // Sends the MIDI note OFF accordingly to the chosen board

          // use if using with ATmega32U4 (micro, pro micro, leonardo...)
          noteOn(midiCh, note + i, 0);  // channel, note, velocity
          MidiUSB.flush();

        }
        buttonPState[i] = buttonCState[i];
      }
    }
  }
}

////
// POTENTIOMETERS
void potentiometers() {


  for (int i = 0; i < NPots; i++) { // Loops through all the potentiometers

    potCState[i] = analogRead(potPin[i]); // reads the pins from arduino

    midiCState[i] = map(potCState[i], 0, 1023, 0, 127); // Maps the reading of the potCState to a value usable in midi

    potVar = abs(potCState[i] - potPState[i]); // Calculates the absolute value between the difference between the current and previous state of the pot

    if (potVar > varThreshold) { // Opens the gate if the potentiometer variation is greater than the threshold
      PTime[i] = millis(); // Stores the previous time
    }

    timer[i] = millis() - PTime[i]; // Resets the timer 11000 - 11000 = 0ms

    if (timer[i] < TIMEOUT) { // If the timer is less than the maximum allowed time it means that the potentiometer is still moving
      potMoving = true;
    }
    else {
      potMoving = false;
    }

    if (potMoving == true) { // If the potentiometer is still moving, send the change control
      if (midiPState[i] != midiCState[i]) {

        // Sends  MIDI CC 
        // Use if using with ATmega32U4 (micro, pro micro, leonardo...)
        controlChange(midiCh, cc + i, midiCState[i]); //  (channel, CC number,  CC value)
        MidiUSB.flush();

        potPState[i] = potCState[i]; // Stores the current reading of the potentiometer to compare with the next
        midiPState[i] = midiCState[i];
      }
    }
  }
}


// if using with ATmega32U4 (micro, pro micro, leonardo...)


// Arduino MIDI functions MIDIUSB Library
void noteOn(byte channel, byte pitch, byte velocity) {
  midiEventPacket_t noteOn = {0x09, 0x90 | channel, pitch, velocity};
  MidiUSB.sendMIDI(noteOn);
}

void noteOff(byte channel, byte pitch, byte velocity) {
  midiEventPacket_t noteOff = {0x08, 0x80 | channel, pitch, velocity};
  MidiUSB.sendMIDI(noteOff);
}

void controlChange(byte channel, byte control, byte value) {
  midiEventPacket_t event = {0x0B, 0xB0 | channel, control, value};
  MidiUSB.sendMIDI(event);
}

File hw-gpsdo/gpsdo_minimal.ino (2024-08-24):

/*
 Arduino Controlled GPS Corrected Generator
 
 Permission is granted to use, copy, modify, and distribute this software
 and documentation for non-commercial purposes.

 Based on the projects: 
 W3PM (http://www.knology.net/~gmarcus/) &
 SQ1GU (http://sq1gu.tobis.com.pl/pl/syntezery-dds/44-generator-si5351a)

 Updates from SQ5NRY:
 - removed display and buttons
 - exposed the initial freq. correction delta
 - added a duplicated PPS output via GPIO
 - minor refactoring
*/

#include <TinyGPS++.h>
#include <string.h>
#include <ctype.h>
#include <avr/interrupt.h>
#include <avr/io.h>
#include <Wire.h>
#include <si5351.h>

TinyGPSPlus gps;
Si5351 si5351;

#define LED_PPS 12
#define LED_ACC 11
#define ppsPin 2

unsigned long XtalFreq = 100000000;
long correction = 124000;
unsigned long mult = 0;
unsigned long Freq = 40000000;  //main 40MHz output
unsigned int tcount = 0;
unsigned int tcount2 = 0;
int validGPSflag = false;
boolean GPSstatus = true;
byte new_freq = 1;
unsigned long pps_correct;
byte pps_valid = 1;
float stab_float = 1000;

void setup() {

  pinMode(LED_PPS, OUTPUT);
  pinMode(LED_ACC, OUTPUT);
  digitalWrite(LED_ACC, HIGH);  //make a quick flash on boot to say I'm alive
  digitalWrite(LED_PPS, HIGH);
  delay(500);
  digitalWrite(LED_ACC, LOW);
  digitalWrite(LED_PPS, LOW);

  TCCR1B = 0;              //disable Timer5 during setup
  TCCR1A = 0;              //reset
  TCNT1 = 0;               //reset counter to zero
  TIFR1 = 1;               //reset overflow
  TIMSK1 = 1;              //turn on overflow flag
  pinMode(ppsPin, INPUT);  //inititalize GPS 1pps input
  digitalWrite(ppsPin, HIGH);

  si5351.init(SI5351_CRYSTAL_LOAD_8PF, 0, correction);
  si5351.drive_strength(SI5351_CLK1, SI5351_DRIVE_8MA);

  Serial.begin(9600);

  //set CLK0 to output 2.5MHz
  si5351.set_ms_source(SI5351_CLK0, SI5351_PLLA);
  si5351.set_freq(250000000ULL, SI5351_CLK0);
  si5351.set_ms_source(SI5351_CLK1, SI5351_PLLB);
  si5351.set_freq(Freq * SI5351_FREQ_MULT, SI5351_CLK1);
  si5351.update_status();

  delay(1000);
  GPSproces(6000);

  if (millis() > 5000 && gps.charsProcessed() < 10) {
    delay(5000);
    GPSstatus = false;
  }

  if (GPSstatus == true) {
    do {
      GPSproces(1000);
    } while (gps.satellites.value() == 0);

    attachInterrupt(0, PPSinterrupt, RISING);
    TCCR1B = 0;
    tcount = 0;
    mult = 0;
    validGPSflag = 1;
  }
}

void loop() {
  if (tcount2 != tcount) {
    tcount2 = tcount;
    pps_correct = millis();
  }
  if (tcount < 4) {
    GPSproces(0);
  }

  if (new_freq == 1) {
    correct_si5351a();
    new_freq = 0;
    if (abs(stab_float) < 1) {
      digitalWrite(LED_ACC, HIGH);
    }
    if (abs(stab_float) > 1) {
      digitalWrite(LED_ACC, LOW);
    }
  }

  if (new_freq == 2) {
    update_si5351a();
    new_freq = 0;
  }

  if (millis() > pps_correct + 1200) {
    pps_valid = 0;
    pps_correct = millis();
  }
}

byte stab_count = 44;
void PPSinterrupt() {
  togglePpsLed();
  tcount++;
  stab_count--;

  if (tcount == 4)  //start counting the 2.5MHz signal from Si5351A CLK0
  {
    TCCR1B = 7;  //clock on rising edge of pin 5
  }

  if (tcount == 44)  //the 40 second gate time elapsed - stop counting
  {
    TCCR1B = 0;  //turn off counter
    if (pps_valid == 1) {
      XtalFreq = mult * 0x10000 + TCNT1;  //calculate correction factor
      new_freq = 1;
    }
    TCNT1 = 0;  //reset count to zero
    mult = 0;
    tcount = 0;  //reset the seconds counter
    pps_valid = 1;
    Serial.begin(9600);
    stab_count = 44;
    calculateCorrection();
  }
}

bool ppsLed = true;
void togglePpsLed() {
  if (ppsLed) {
    digitalWrite(LED_PPS, HIGH);
  } else {
    digitalWrite(LED_PPS, LOW);
  }
  ppsLed = !ppsLed;
}

ISR(TIMER1_OVF_vect) {
  mult++; 
  TIFR1 = (1 << TOV1);  //clear overlow flag
}

void calculateCorrection() {
  long stab = XtalFreq - 100000000;
  stab = stab * 10;
  if (stab > 100 || stab < -100) {
    correction = correction + stab;
  } else if (stab > 20 || stab < -20) {
    correction = correction + stab / 2;
  } else correction = correction + stab / 4;

  long pomocna = 10000 / (Freq / 1000000);
  stab *= 100;
  stab /= pomocna;
  stab_float = float(stab) / 10;
}

//set new frequency
void update_si5351a() {
  si5351.set_freq(Freq * SI5351_FREQ_MULT, SI5351_CLK1);
}

//apply frequency correction
void correct_si5351a() {
  si5351.set_correction(correction, SI5351_PLL_INPUT_XO);
}

//read and process NMEA data from GPS
static void GPSproces(unsigned long ms) {
  unsigned long start = millis();
  do {
    while (Serial.available())
      gps.encode(Serial.read());
  } while (millis() - start < ms);
}

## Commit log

2024-08-24 feat: initial commit
    [pluto_biastee.kicad_sch, pluto_clock_buffer.kicad_pcb, pluto_clock_buffer.kicad_sch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]
2024-08-31 readme: updates
    bash script sonar fixes
2024-09-11 readme: bom-pl
2024-10-02 bom humidity script
    [qo100_bom.xlsx]
2024-10-28 readme: humidity sensor
